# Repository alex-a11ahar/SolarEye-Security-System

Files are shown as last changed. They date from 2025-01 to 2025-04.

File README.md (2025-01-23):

## SolarEye-Security-System
### ECEN-403/404 Solar Security System Capstone Project

**A solar-powered security system with a motion-detecting camera. This system provides near real-time video feeds and send automated alerts for suspicious activity through a mobile app, enhancing safety in these areas.**

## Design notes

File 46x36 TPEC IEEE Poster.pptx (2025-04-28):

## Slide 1

SolarEye Security System
Alex Allahar, Zayan Prasla, Jackson Kitchel, Victor Igbokwe
Wonhyeok Jang

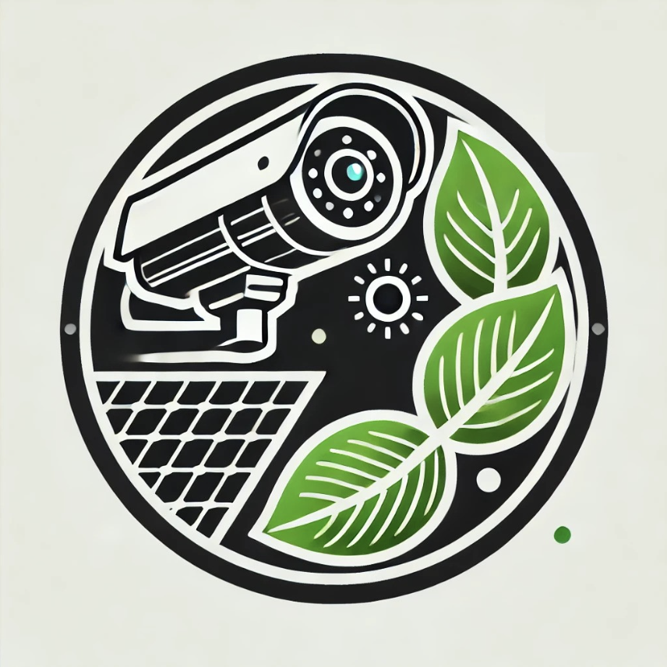
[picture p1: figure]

System Overiew
The SolarEye Security System uses solar-powered lighting, smart surveillance, and mobile alerts for real-time, automated, and low-maintenance security, ensuring safer, smarter public spaces.

Power Distribution
The Power Distribution system draws from a 12-volt battery, the system employs a buck converter [see Figure 3(A)] to step down the voltage to 5 volts, ensuring stable and efficient power delivery. This regulated 5-volt supply is essential for operating key components, including the charging ports and the Raspberry Pi. To enhance functionality, the LED lights are integrated through a dedicated PCB [see Figure 3(B)], which allows the Raspberry Pi to precisely control their operation. This setup enables seamless coordination between power distribution and system control, optimizing performance and efficiency.
A: Buck Converter PCB – Efficiently steps down 12V to a stable 5V supply.
B: Boost Converter PCB – Enables voltage regulation and control via the Raspberry Pi.

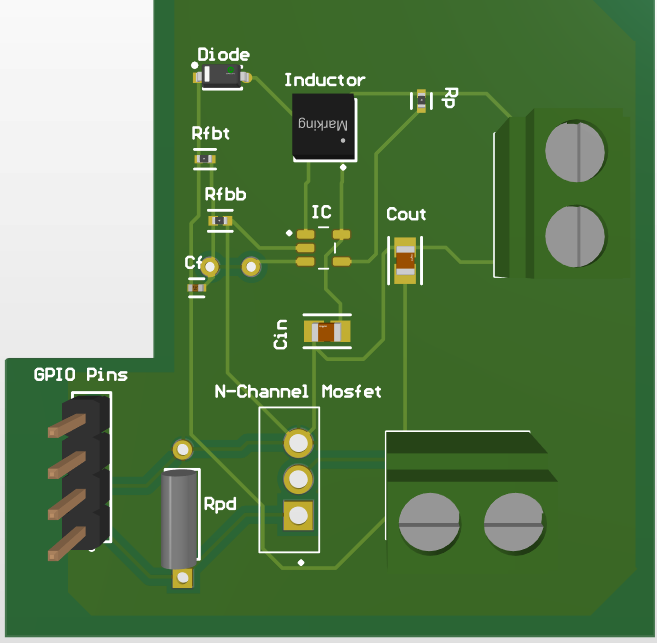
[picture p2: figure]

Solar Generation
The Solar power generation subsystem serves as the central power source within our project. The subsystem is responsible for the solar panel, charging circuit PCB and supplying power to the 12-volt battery. The 100W solar panel is connected directly to the charging circuit PCB which regulates the power and supplies the 12-volt battery with a safe and efficient supply voltage. Additionally, the voltage and current supply from the solar panel as well as the battery are monitored by the charging circuit. These data points are then output by the PCB to be read and processed by the Raspberry Pi 4B. The main components of the schematic below are as follows:
A: BQ24650, which serves as the Maximum Power Point Tracking (MPPT) aspect of the circuit
B: ACS723 current sensor IC chips, placed at the input and output of the circuit

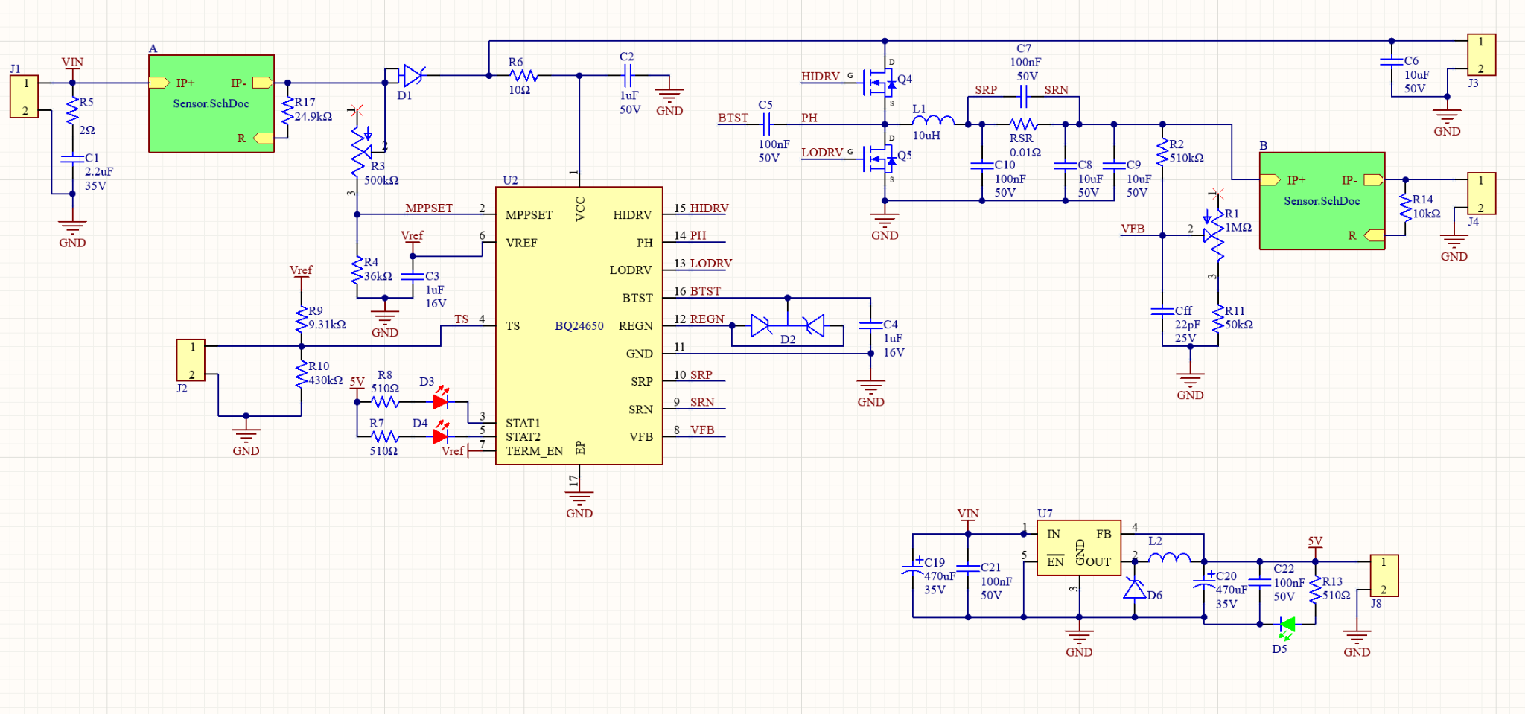
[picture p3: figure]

SolarEye App
The SolarEye App interfaces with the SolarEye Security System via Firebase, allowing comprehensive control over the system's camera and LED deterrence features. The home page provides an overview of Event History and Charging Statistics for the Solar Panel and Battery. In the Event History section, all recorded events are listed, complete with timestamps and event types. To ensure maximum security, the app's backend is fortified with email verification, two-step authentication, and SMS verification.

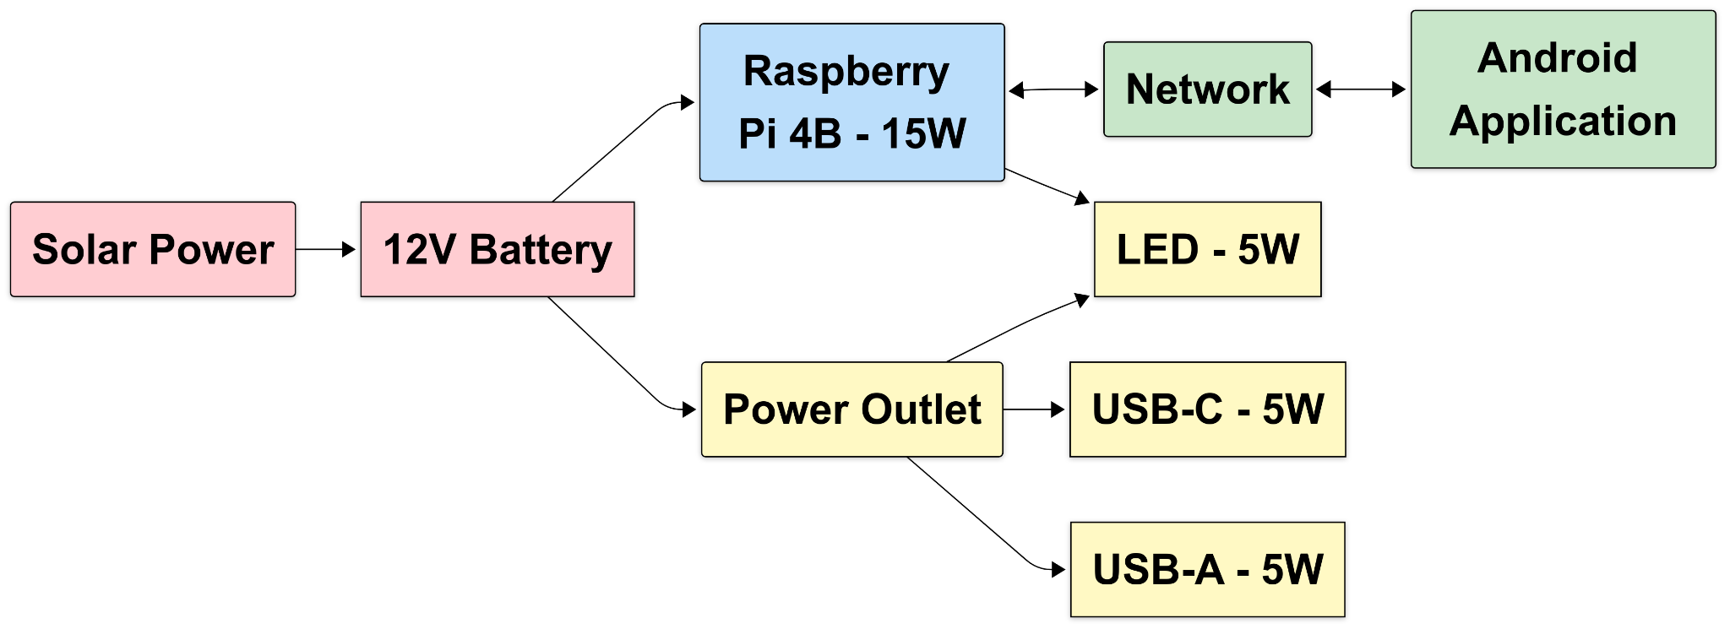
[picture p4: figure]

Figure 1. System Diagram

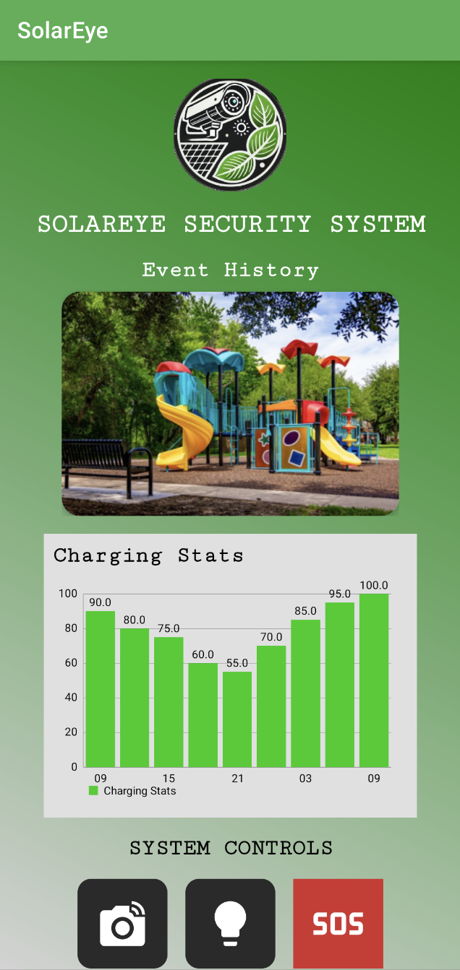
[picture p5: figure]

Figure 7. SolarEye App Home Page

Security
The SolarEye Security System has two modes: Passive Security and Active Surveillance. In Passive Mode, a PIR sensor triggers automated video capture, event logging, and Firebase storage. In Active Mode, users enable real-time streaming with OpenCV motion detection, sending alerts to Firebase for immediate response. This ensures efficient, continuous monitoring with optimized power use.

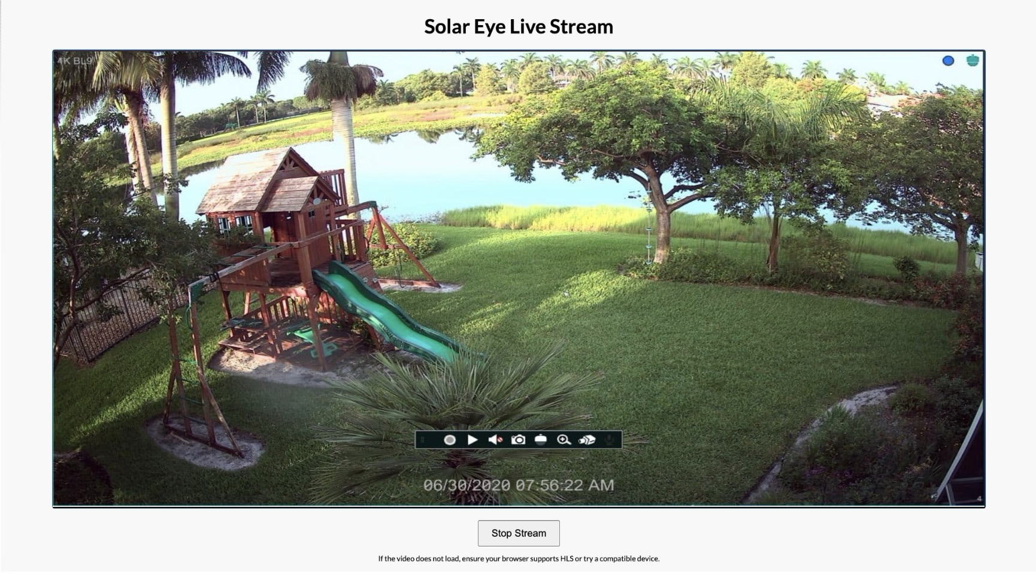
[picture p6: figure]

Figure 2: Livestream Layout

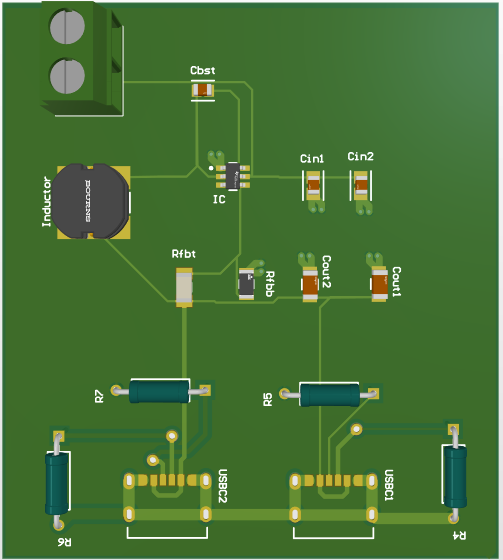
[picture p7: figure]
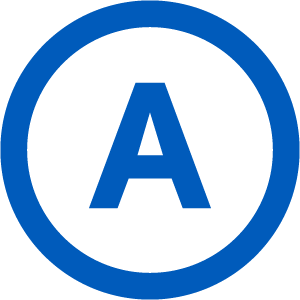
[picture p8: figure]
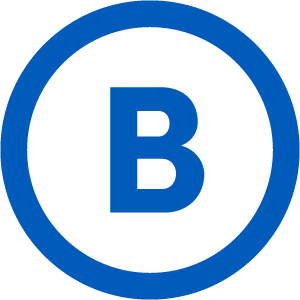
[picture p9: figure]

Figure 3. View of Printed Circuit Boards

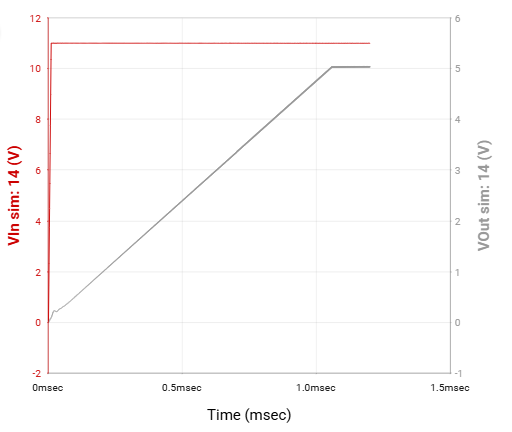
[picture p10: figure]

Figure 4.Simulation Results for the Buck Converter

Figure 5. Solar Power Charging Circuit Schematic

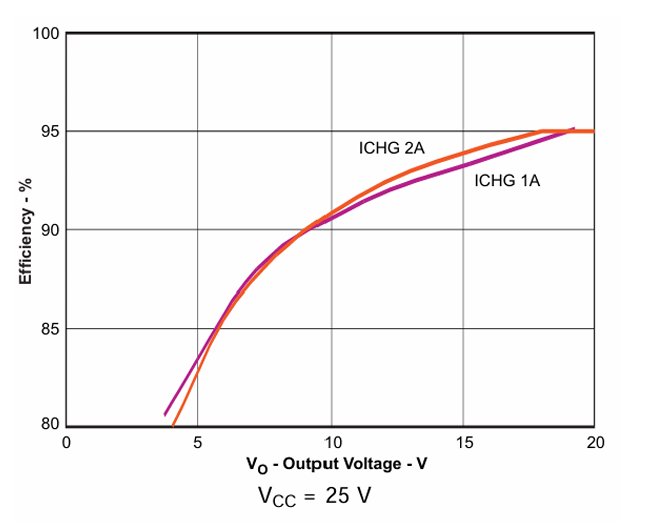
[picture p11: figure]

Figure 6. Solar Power Charging Circuit Efficiency vs Output Voltage (Taken from MPPT Spec Sheet)

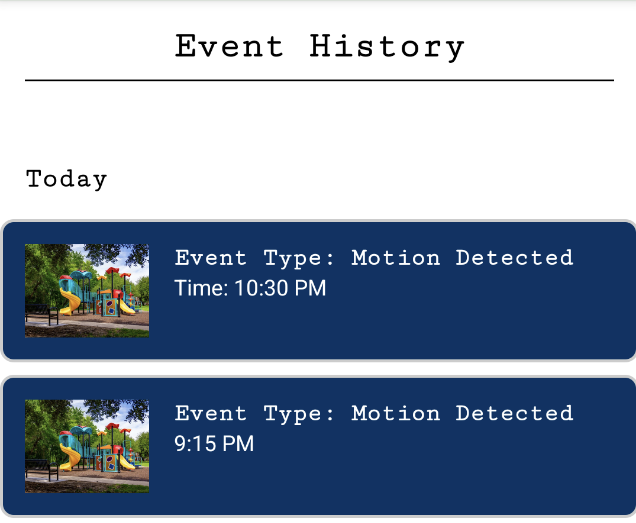
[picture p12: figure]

Figure 8. SolarEye App Event History Page

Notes: Fix Overview diagram

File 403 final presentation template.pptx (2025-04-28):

## ECEN 403 Final Presentation SolarEye Security System Team members: Alex Allahar, Victor Igbokwe, Jackson Kitchel, Zayan Prasla Sponsor: Dr. Jang


## Problem Overview

- A solar-powered security system with a motion-detecting camera. This system provides near real-time video feeds and send automated alerts for suspicious activity through a mobile app, enhancing safety in these areas.

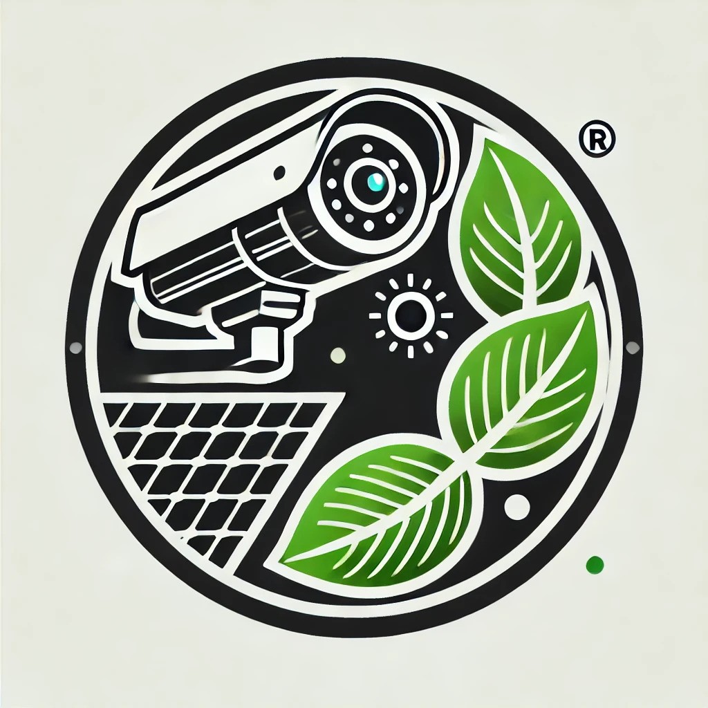
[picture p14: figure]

## System Diagram

Red - Jackson Kitchel (Power Generation)
Yellow - Victor Igbokwe (Power Distribution)
Blue - Alex Allahar (Detection)
Green - Zayan Prasla (Network & Application)

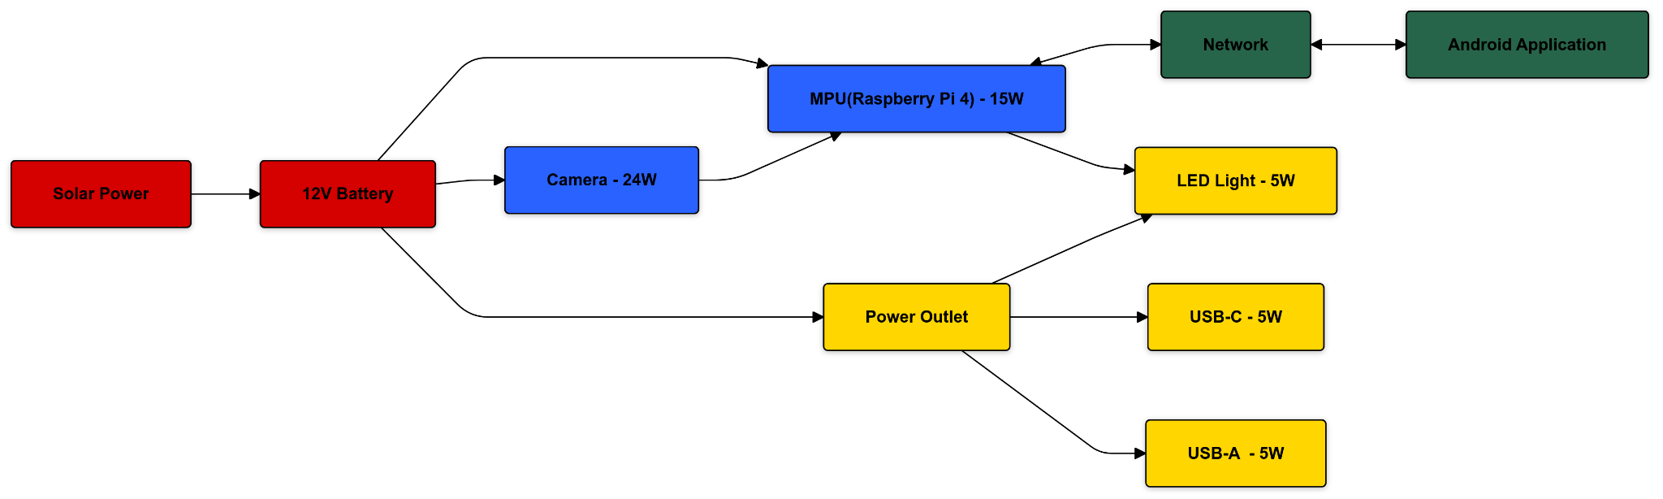
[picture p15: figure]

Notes: This is where task partition is stated, Alex

## Subsystem 1: Power Generation

- PCB responsible for power generation from the solar panel to the battery
- Battery supplies power distribution PCP with 12V
- Charging circuit automatically cuts on/off
- Provides MCU with voltage and current readings at the solar panel and battery

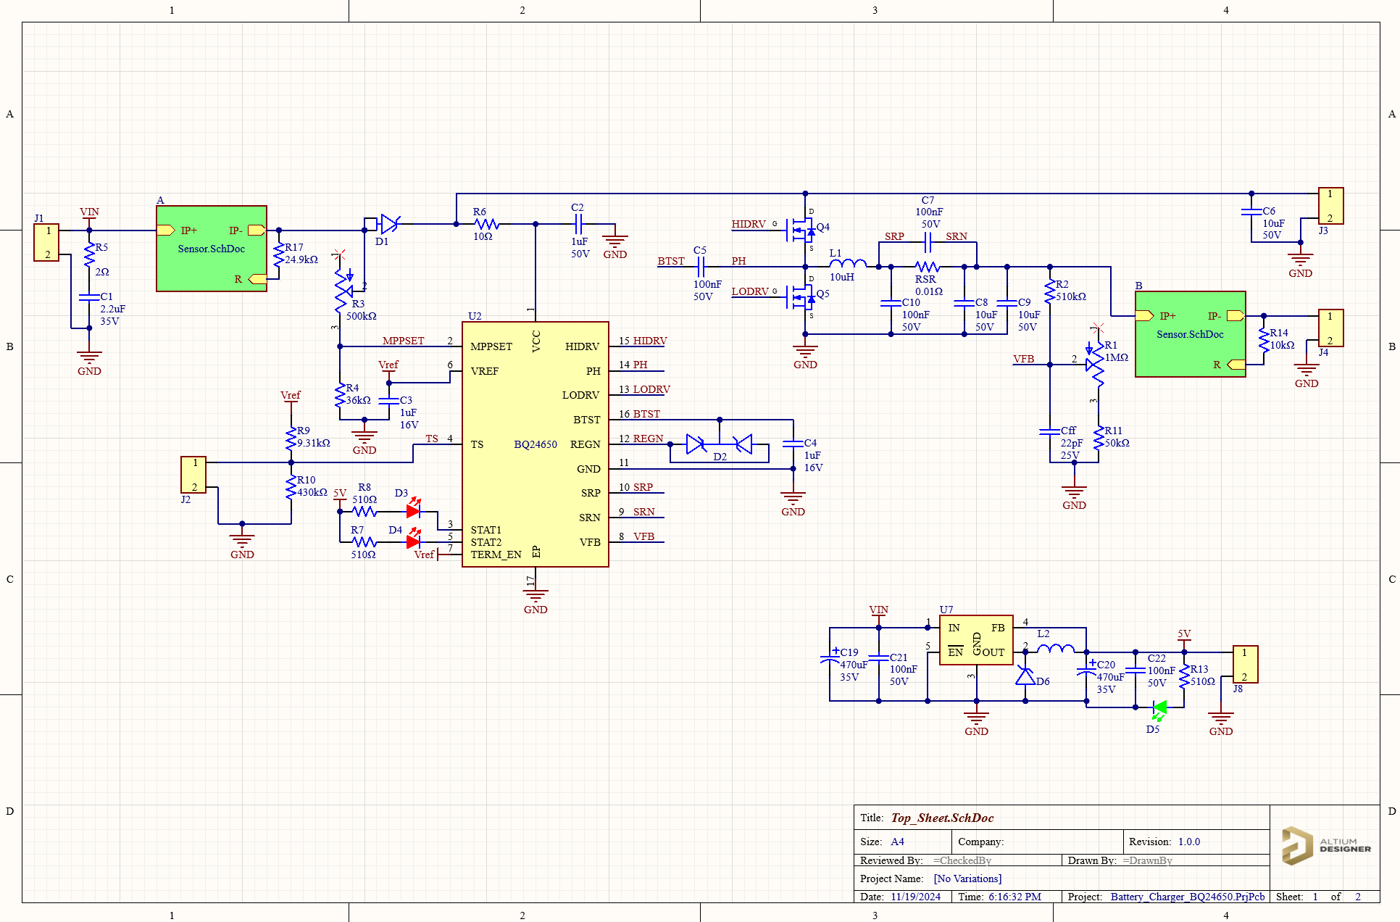
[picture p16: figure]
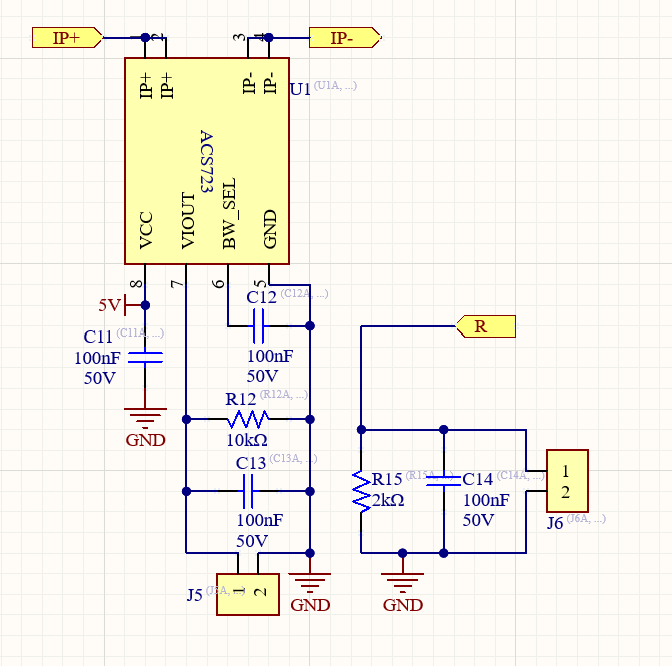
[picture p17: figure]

## Subsystem 1: Power Generation

- Ongoing Tasks:
  - First PCP scrapped
  - Soldering and testing PCB (ie. short circuit, continuity)
- To do in 403:
  - Battery charging test
  - Cut on/off test
  - Demo
- To do in 404:
  - Integrate power with distribution subsystem
  - Integrate voltage/current readings with MCU subsystem

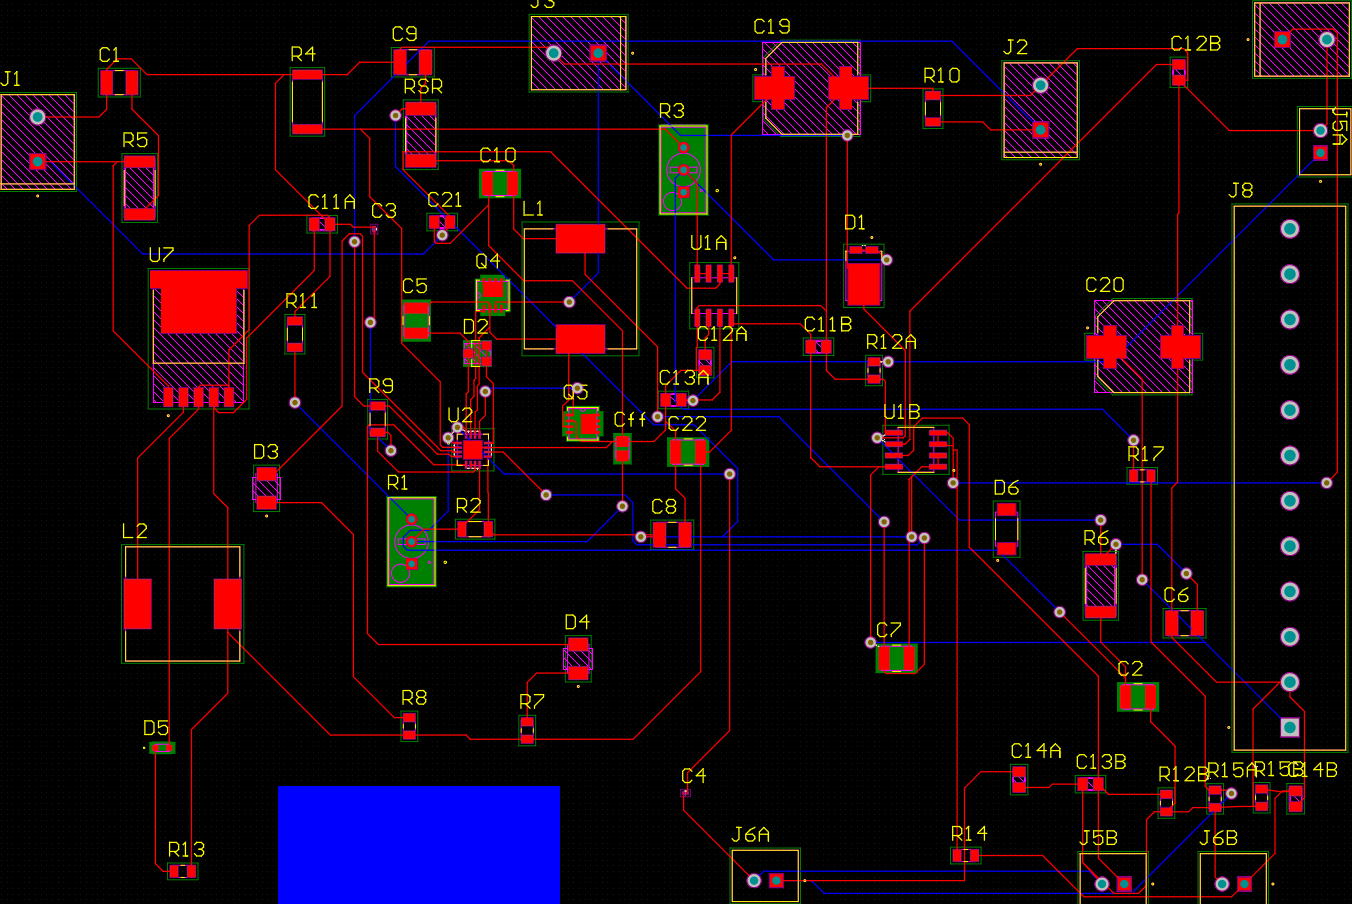
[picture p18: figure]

## Subsystem 2: Power Distribution

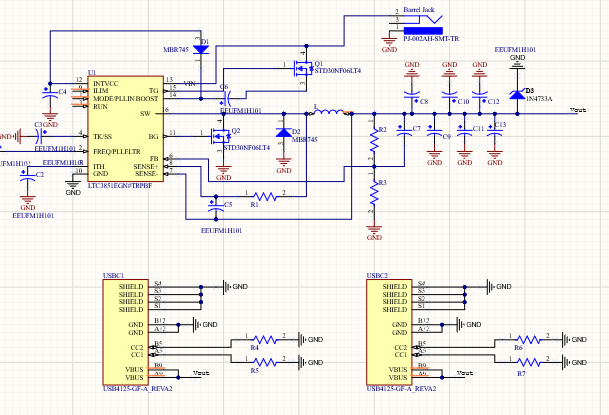
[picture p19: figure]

## Power Distribution Cont.

Completed Tests
- Continuity Test: Use a multimeter to check continuity between connected pads and traces to ensure no open connections exist.
- Short Circuit Test: Verify there are no shorts between the power (5V and 12V rails) and ground. Measure resistance between 5V and GND and 12V and GND. It should not show a short (low resistance).
Concerns
- Vin Connection: Experiencing difficulties with the connection between the MOSFET and the Vin pin of the IC chip.
Proposed Solution
- Perf Board: Use an external Perf board to solder a connection between the mosfet and Vin.
To Do (403)
- Output Voltage Test
- Load Test
To Do (404)
- Voltage Regulator load Components
- Integration with other subsystems

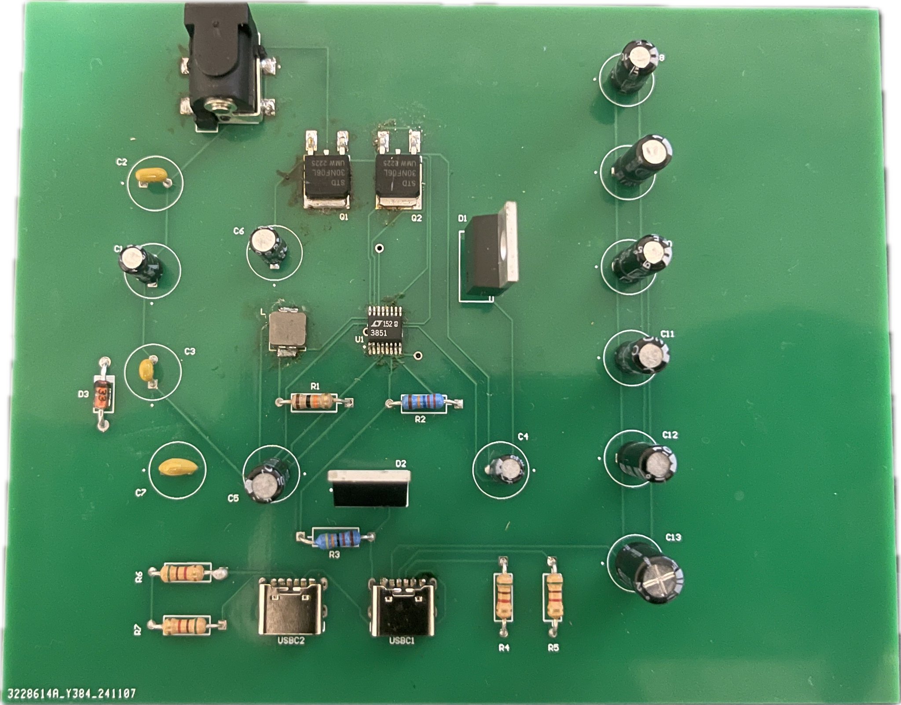
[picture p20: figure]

## Detection: Modes of Operations

Low-Power Mode
Passive (Security)
- PIR Sensor Activated
- Automated Video Capture
  - Fixed / Variable
- Generate Thumbnails
- Local Event History
- Store Footage on Firebase

Operational Mode
Active (Surveillance)
- User Activated
- Real-Time Video Stream
- OpenCV Motion Detection
- Send Alert to Firebase

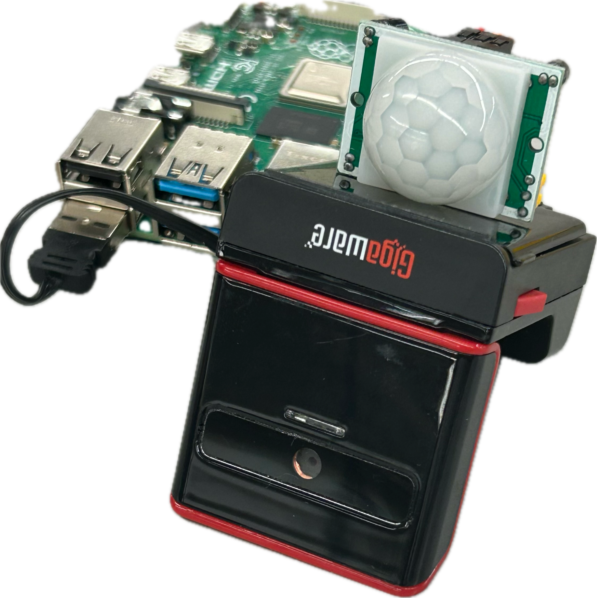
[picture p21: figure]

## Detection: Test Cases

Completed:
  - Validate PIR Sensor functional up to 5 ft, FOV, with a FOV of 120°
  - Minimize delay between motion detection and video capture stored on Firebase.
  - Measure Raspberry PI Memory and CPU Usage during Modes of Operation.
To-Do (403):
  - Passive Mode Output

## Subsystem 4: Software/App

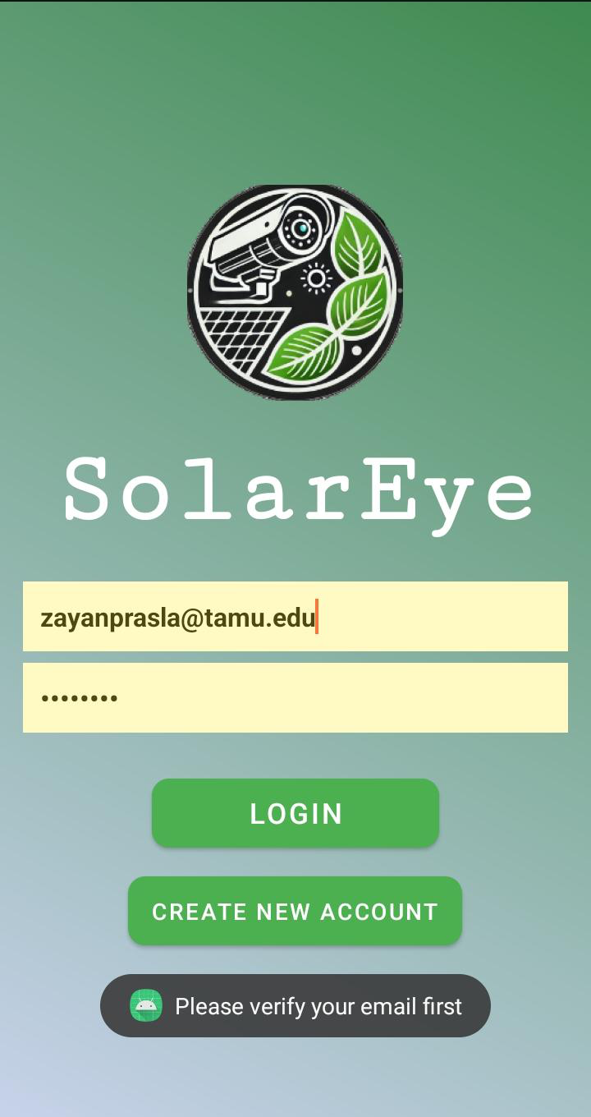
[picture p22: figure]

Login Page:
- User Login saved on Firebase Auth
- Email must be verified to login
- User remains logged in until they manually log out

Email Verification:

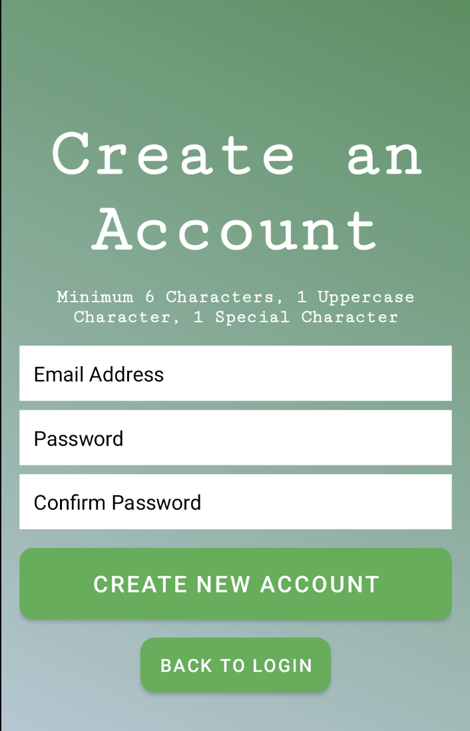
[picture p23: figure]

Account Creation:
- Email Verification
- Verification Link expiration
- Password Policy

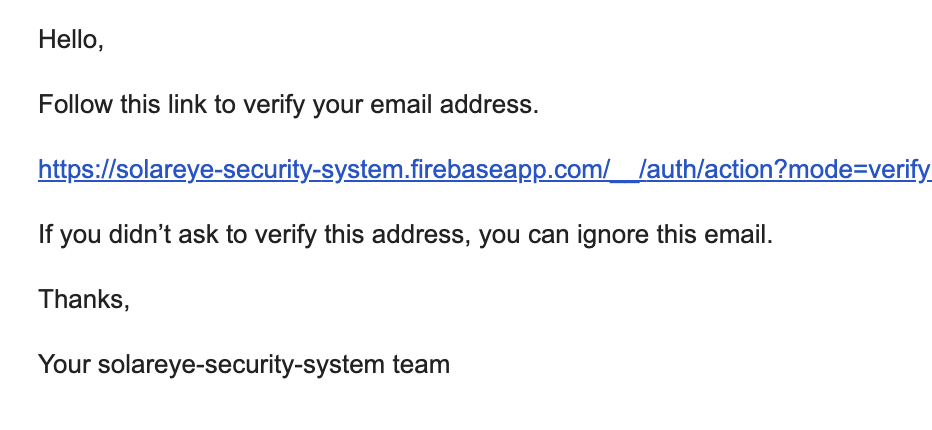
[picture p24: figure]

## Subsystem 4: App Main Page


Main Page:
- Latest thumbnail displayed
- Charging Statistics
- System Controls


Event History:
- Events sectioned by date recorded
- Event Type and Time


Settings:
- Log Out
- Email Change
- Password Reset

## Subsystem 4: App System Controls


- On/Off controls for Camera and LED Light (not yet connected)
- SOS Emergency Call (connected directly to device)

## Execution and Validation Status


## Remaining Tasks

- Summarize what remains to be completed for your subsystem design, assembly, test, and validation by Project Demo date.
- Summarize what key design activity from each subsystem will be completed in 404 (eg. fabrication and assembly of final PCB, full ML model training, in-situ sensor calibration, enclosure design and fabrication, mount 3d-printing)

- Software: FAQ section is left. In 404 the app will be connected to the security system, retrieve live data from Firebase Firestore, and have a better front User Interface.
- Microprocessor/Detection:
- Power Generation:
- Power Distribution:

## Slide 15


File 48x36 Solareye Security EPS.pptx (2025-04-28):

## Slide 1


EQ39

SolarEye Security System
Alex Allahar, Zayan Prasla, Jackson Kitchel, Victor Igbokwe
Wonhyeok Jang


Electrical Engineering

System Overiew
An autonomous solar‑powered, motion‑activated camera system that delivers live video feeds and instant app alerts for reliable off‑grid surveillance.

Power Distribution
The Power Distribution system draws from a 12-volt battery, the system employs a buck converter [see Figure 3(A)] to step down the voltage to 5 volts, ensuring stable and efficient power delivery. This regulated 5-volt supply is essential for supplying adequate power to the Raspberry Pi. To enhance functionality, the LED lights and cooling fans are integrated through a dedicated relay control PCB [see Figure 3(B)], which allows the Raspberry Pi to precisely control their operation. This setup enables seamless coordination between power distribution and system control, optimizing performance and efficiency.
A: Buck Converter PCB – Efficiently steps down 12V to a stable 5V supply.
B: Relay Control PCB – Allows the user to control via the Raspberry Pi.


Figure 3. View of Printed Circuit Boards

Solar Generation
The Solar power generation subsystem serves as the central power source within our project. The subsystem is responsible for the solar panel, charging circuit PCB and supplying power to the 12-volt battery. The 100W solar panel is connected directly to the charging circuit PCB which regulates the power and supplies the 12-volt battery with a safe and efficient supply voltage. Additionally, the voltage and current supply from the solar panel as well as the battery are monitored by the charging circuit. These data points are then output by the PCB to be read and processed by the Raspberry Pi 4B. The main components of the schematic below are as follows:
A: BQ24650, which serves as the Maximum Power Point Tracking (MPPT) aspect of the circuit
B: ACS723 current sensor IC chips, placed at the input and output of the circuit


SolarEye App
The SolarEye App interfaces with the SolarEye Security System via Firebase, allowing comprehensive control over the system's camera and LED deterrence features. The home page provides an overview of Event History and Charging Statistics for the Solar Panel and Battery. In the Event History section, all recorded events are listed, complete with timestamps and event types. To ensure maximum security, the app's backend is fortified with email verification, two-step authentication, and SMS verification.


Figure 7. SolarEye App Home Page

Figure 1. System Diagram

Modes of Operation
Low Power Mode (≈ 32.8 h runtime)
- Logs only when an event occurs and its duration (no video). Timestamps and durations available in the app; LED deterrence flashes rapidly.
Motion Detection Mode (Default) (≈ 30.7 h runtime)
- Continuously monitors via PIR sensor, captures short videos on motion, and uploads them.
- Process: PIR → log event → record until 2 s after no motion → save H.264 locally → convert & upload MP4 to Firebase → app shows time stamped video history.
Livestream Mode (≈ 22.2 h runtime)
- Provides real‑time video streaming on demand.
- Tap “Livestream”; Pi starts HLS streaming and sends the link to the app.


Figure 4. Buck Converter Voltage Regulation graph

Figure 5. Solar Power Charging Circuit Schematic


Figure 6. Solar Power Charging Circuit Efficiency vs Output Voltage (Taken from MPPT Spec Sheet)


Figure 8. SolarEye App Event History Page


Figure 2. Livestream UI Layout

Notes: A battery-powered IoT security system offering three operation modes that balance power consumption against functionality.

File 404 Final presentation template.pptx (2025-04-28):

## ECEN 404 Final Presentation Team 65: Solar Playground with Security System Team Members: Zayan Prasla, Alex Allahar, Jackson Kitchel, Victor Igbokwe Sponsor: Wonhyeok Jang TA: Zian Wang

## Problem Overview

A solar-powered security system with a motion-detecting camera. This system provides near real-time video feeds and sends automated alerts for suspicious activity through a mobile app, enhancing safety in these areas. It solves the problem of unreliable surveillance in remote or off-grid locations by offering an autonomous, low-maintenance solution.


## Integrated Project Diagram


Figure 1: Full System Overview

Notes: Picture (or collection of pictures) or drawing of system
Major components labeled
Show how user connects (ui screens, pictures, etc)
Label major connections/interfaces

## Integrated Project Diagram (Hardware)


Figure 2: Hardware Overview

Intake Fan

Buck Converter PCB

Solar Charging PCB

Power Switch

Relay control PCB

Raspberry Pi 4 B

CSI Pi Camera

PIR Sensor

Exhaust Fan

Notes: Picture (or collection of pictures) or drawing of system
Major components labeled
Show how user connects (ui screens, pictures, etc)
Label major connections/interfaces

## Integrated System Diagram (Software)


Figure 3: Homepage with updating Event thumbnail and updating Charging Statistics

Figure 6: Modes of Operation and System Controls with successful communication


Figure 4: Event History Page with live stream capability and playable videos

Figure 5: Video Player from the app


## Power Generation - Jackson Kitchel

Designed & Built:
- Designed and built a charging circuit capable of charging a 12V battery using a 100W solar panel.
- Implemented Maximum Power Point Tracking (MPPT) using the BQ24650 IC chip
- Implemented 2 current and voltage sensors using the ACS723 IC chips along with ADC
Tested & Validated:
- Charging voltage test completed along with high/low voltage cutoffs. Sensors tested with MCU. Battery life to be tested.
Challenges & Solutions:
- Redesigned charging circuit to solve incorrect capacitor problem, along with making the circuit more compact.

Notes: Flask (HTTP)

Serves web interface for live video access and control

Runs lightweight, multithreaded server for responsiveness

FFmpeg + HLS Streaming

Captures video via libcamera-vid and streams with FFmpeg

Outputs low-latency .m3u8 segments for browser playback using hls.js

## Power Generation - Jackson Kitchel


Figure 7: Charging Circuit Schematic

Figure 8: Current Sensor Schematics


Figure 9: PCB Design

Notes: Flask (HTTP)

Serves web interface for live video access and control

Runs lightweight, multithreaded server for responsiveness

FFmpeg + HLS Streaming

Captures video via libcamera-vid and streams with FFmpeg

Outputs low-latency .m3u8 segments for browser playback using hls.js

## Power Generation - Jackson Kitchel

Figure 10: Charging Voltage vs Solar Panel Voltage Graph

Figure 11: Old PCB Design


Figure 12: Charging Voltage Output


Figure 13: New PCB Design

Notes: Flask (HTTP)

Serves web interface for live video access and control

Runs lightweight, multithreaded server for responsiveness

FFmpeg + HLS Streaming

Captures video via libcamera-vid and streams with FFmpeg

Outputs low-latency .m3u8 segments for browser playback using hls.js

## Power Distribution - Victor Igbokwe

Designed & Built:
- Designed and built a buck converter using the Texas Instruments TPS563200 DCR regulator to provide stable 5V output for embedded systems.
- Implemented a relay control module using an N-channel MOSFET to act as a switch, enabling the Raspberry Pi to control the on/off state of external loads.
Tested & Validated:
- Buck converter Voltage and load regulation tests, Relay Control module Load regulation test, measured time delay between Pi signal and device activation.
Challenges & Solutions:
- Safety for repairs: Installed a switch button to the Junction box to shut down all power flowing through the system
- Buck Converter: Re-designed to ensure correct functionality

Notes: Flask (HTTP)

Serves web interface for live video access and control

Runs lightweight, multithreaded server for responsiveness

FFmpeg + HLS Streaming

Captures video via libcamera-vid and streams with FFmpeg

Outputs low-latency .m3u8 segments for browser playback using hls.js

## Power Distribution - Victor Igbokwe


Figure 14: Voltage regulation graph

Initial MPU Remote Access time delay | 1.26 minutes
Raspberry PI 4B input Voltage Range(V) | 4.75 - 5.25


Figure 15: Buck Converter


Figure 16: Load regulation graph

* 5% Tolerance

## Power Distribution - Victor Igbokwe


Figure 17: Relay control load regulation graph

Time delay between MPU signal and device activation
0.4 seconds


Figure 18: Relay control module PCB


Figure 19: Use of N-Channel Mosfet diagram

## Edge Processing Unit - Alex Allahar

Designed & Built:
- Integrated PIR sensor (I2C), voltage sensor (I2C), camera (CSI), LED and fans (GPIO) with a Raspberry Pi 4B to enable the following features:
  - Low-Power Mode
  - Motion Detection
  - Live Streaming
  - LED Deterrence
Tested & Validated:
- Calibrated sensors & fans, ADC communication, Camera quality, power consumption, overall hardware-software latency
Challenges & Solutions:
- CPU Overload: Solved with multi-threading and modes of operation controls.
- MPU Overheating: Fans for Overheating.
- Camera: Replaced Camera (USB to CSI), video format selection, Live streaming delay

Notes: Expand on the Modes of Operation Points

Livestream:
Host a Flask Server with HTTP web interface for live video access and control
Captures video and streams with FFmpeg with HLS browser playback for viewing via the HTTP Flask Url

## Edge Processing Unit - Alex Allahar

Figure 20: Requirements Validation Table

Requirements | Target | Measured | Status
Motion to App Delay | < 1 s | 0.0784 s | Passed
Video Upload Latency | < 3 s | 1.2951 s | Passed
Real Event vs. Video Capture Ending | < 5 s | 4.03 s | Passed
Livestream Delay | < 5 s | ~7.8 s | Failed
Motion Detection Range | 12 ft | 16 ft | Passed
Fans Power Consumption | < 5 W | 8.8 W | Failed
Pi Power Consumption (Low Power) | < 20 W | 9.4 W | Passed
Pi Power Consumption (Default) | < 20 W | 10.75 W | Passed
Pi Power Consumption (Livestream) | < 20 W | 18.25 W | Passed

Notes: Validation Meaning:
System provides near real-time motion detection to alert system with minimal latency
The biggest downside to the user experience is the Live Streaming delay
The power consumption of all three modes of operation are less that 20 W, this target was chosen due the battery specs if less that 20 W are at max constant use for a given mode of operation the system in theory should be able to run for 25 hrs on the battery ensure that it can survive the night while the panel is unable to charge.

Power consumption was calculated by measuring the current of the system under load in Lab.

## Android Application - Zayan Prasla

Designed & Built:
- Created a secure Firebase Authentication system for account creation, email verification, password reset, password policy and persistent login
- Developed camera, LED, and SOS control features, with Modes of Operation for system power usage
- Implemented real-time event history with video thumbnail previews and video playback
Tested & Validated:
- Verified user authentication flows, password policies, and email verification timeouts
- Confirmed Firestore integration for reading and writing system control states
- Ensured proper display and playback of video thumbnails from Firestore Database URLs
Challenges & Solutions:
- Firestore path issues: Fixed with proper document structure and logging
- Video Player issues: Solved by having the mcu create video url links for the app to open from Firestore Database.

## Android Application - Zayan Prasla

App Features Validation Table:

Requirements | Spec | Measured
Authentication Timeout | Email verification link expires in 5 min | Verified expiration at ~5:01 min
Password policy enforcement | Min 6 char, 1 capital, 1 symbol, 1 number | 100% rejection rate on invalid attempts
Video event thumbnail loading | Thumbnail shown within 2 sec | Avg load time: 1.2 sec, max: 1.8 sec
Battery graph recency | Only last 24h voltage data shown | Consistently accurate range filter applied
Mode change response (Firestore write) | Update reflected in < 1.5 sec | Avg: 0.9 sec, Min: 0.6 sec, Max: 1.4 s

Figure 21: App Features Validation Table:

## Integrated System Results

End-to-End System Operation (Low Power):
Low Power Mode Predicted Run Time ≈ 32.8 hours
Lower Power Mode (User Experience):
- Able to see when the event occurred, and duration via but no video.
- LED Deterrence is available, flashes the LED rapidly.


Figure 22: LED Deterrence Active


Figure 23: Event History

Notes: This section shows end-to-end system operation
Show and provide details on a few important end-to-end use scenarios that you developed and validated. Giving results (be quantitative here – results for key performance indicators … time to complete task, overall accuracy of task, success/fail measures)

About 2 minutes total

The run time is calculated given the power consumption of Pi combined with power consumption of Fans

## Integrated System Results

End-to-End System Operation (Default):
Motion Detection Mode Predicted Run Time ≈ 30.69 hours
Motion Detection Mode (Pipeline):
- PIR Sensor detects motion → event is logged → camera starts recording → recording stops after 2 seconds of no motion → video saved locally(h264) → uploaded to Firebase(mp4) → app receives video with timestamp → user views it in event history.


Figure 24: Motion Detection Capture


Figure 25: Notification Packaged for App

Figure 26: Event History

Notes: This section shows end-to-end system operation
Show and provide details on a few important end-to-end use scenarios that you developed and validated. Giving results (be quantitative here – results for key performance indicators … time to complete task, overall accuracy of task, success/fail measures)

If Low Power Mode or Livestreaming are triggered by the user, motion detection will be active.

About 2 minutes total

The total Run Time is calculated by combine hardware component power consumption and Pi power consumption given the 50Ah 12V battery

## Integrated System Results

End-to-End System Operation (Livestream):
Livestream Mode Predicted Run Time ≈ 22.18 hours
Lower Power Mode (User Experience):
- User click Livestream Button - HTTP Server Activates - Pi starts HLS Stream Protocol - Stream HTTP Link create/sent to app - user can access stream by clicking on the Link

Figure 25: LIvestream HTTP Server Startup

Figure 26: LIvestream HTTP Link to Firebase


Figure 27: LIvestream UI

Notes: This section shows end-to-end system operation
Show and provide details on a few important end-to-end use scenarios that you developed and validated. Giving results (be quantitative here – results for key performance indicators … time to complete task, overall accuracy of task, success/fail measures)

About 2 minutes total

Livestream:
Host a Flask Server with HTTP web interface for live video access and control
Captures video and streams with FFmpeg with HLS browser playback for viewing via the HTTP Flask Url

## Conclusions

Changes from original System design:
- Buck Converter IC chip change leading to re-design of Buck converter
- Relay control module PCB added to system design
- Charging Circuit redesigned to solve capacitor problem and consolidate PCB
- ADC added to system to allow communication between current sensor IC chips and MCU
Current Status:
- Integration Complete
- Operational Testing Complete
- Validation Complete
- Edge Case Testing in Progress

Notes: List issues encountered that required changes from system described in Conops, FSR/ICD and resulting system design changes
Current status (eg. integration/test/validation complete; Integration complete, but BT comm not fully validated; Repeating testing for replacement PCB, integration/validation to be completed in 1 week)

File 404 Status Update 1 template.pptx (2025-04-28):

## Team 65: Solar Playground with Security System Bi-Weekly Update 1 Team Members: Zayan Prasla, Alex Allahar, Jackson Kitchel, Victor Igbokwe Sponsor: Wonhyeok Jang TA: Zien Wang


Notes: Michelle

## Project Summary

A solar-powered security system with a motion-detecting camera. This system provides near real-time video feeds and send automated alerts for suspicious activity through a mobile app, enhancing safety in these areas.


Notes: Kyle

## Subsystem Overview

Red - Jackson Kitchel (Power Generation)
Yellow - Victor Igbokwe (Power Distribution)
Blue - Alex Allahar (Microprocessor & Sensors)
Green - Zayan Prasla (Network & Application)


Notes: Edge processing unit for the system.

## Major Project Changes for 404

- Removed Object Detection
- LED Deterrence
- Adding Cooling

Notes: Bullets on MAJOR changes in project direction due to learning from 403. If stuff didn’t work out now is the time to redirect
-- eg custom to COTS, MCU changes, application change, major change in communication technology, …

## Project Timeline


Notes: High level figure showing where you are at in the project, what’s completed, what’s underway – it should take about 30 seconds to summarize where you are in the timeline

-- Save discussion for subsystem update
-- Save detail for execution plan & validation plan status

## Power Generation Jackson Kitchel

Accomplishments since 403 | Ongoing progress/problems and plans until the next presentation
PCP has been updated to address issues that were found in 403. Parts and PCB has been ordered. | - Solder and test new PCB upon arrival. - Integrate with other subsystems.

## Power Generation Jackson Kitchel

- Problem with footprint and missing
trace to be fixed with new order


## Power Distribution Victor Igbokwe

Accomplishments since 403 | Ongoing progress/problems and plans until the next presentation
Buck Converter system experienced issues due to complexity of IC chip that. New PCB has been designed and ordered using a Texas Instruments IC chip. | Soldering and testing my new buck converter system. Design and order a new PCB that will implement using an N-Channel Mosfet as a switch to control the Security light.

## Power Distribution Victor Igbokwe


Still Developing:
Using N-channel as a switch
- Common Ground between microcontroller and Power supply
- Pull-down resistor at the output pin.
- Setting the output pin to High will allow current flow while setting it to low will disrupt current flow.


## Microprocessor & Sensors Alex Allahar

Accomplishments since 403 | Ongoing progress/problems and plans until the next presentation
Tested and Validation CSI Camera | Integration of Firebases Designing the cooling and housing for MPU, Camera, & Sensors.

## Microprocessor & Sensors

Low-Power Mode
Works
- GPIO Sensors
- Automated Video Capture
  - Fixed / Variable
- Thumbnails Generation
- Local Event History
- Cloud Video Storage

Streaming Mode
Works
- Real-Time LIve Stream
- Live Stream Web Server
- OpenCV Motion Detection
- App Notification
Still Developing
- User Activation via App

## Subsystem 4 Application Zayan Prasla

Accomplishments since 403 | Ongoing progress/problems and plans until the next presentation
Removed fixed event history examples from 403 and connected it to Firebase for live updates. Added reset password for the login page and connected it via backend to the user’s specific email. | App to microprocessor connection via Firebase Camera and LED controls Live stream Constantly improving frontend UI as well

## Subsystem 4 Application Zayan Prasla

Backend/Security
Works
- User Login and Account Creation
  - Password Policy Enforced
  - User accounts stays logged in until manually logged out
- Email Verification
  - Verification link expires after 5 minutes
- Internet Connection
- Password Reset
- Email Address Change
- Event History connected to Firebase Realtime Database
Still Developing
- App to Microprocessor connection
- New Sign-in Methods
- SMS Verification
- 2-step verification

Frontend
Works
- Login, Create Account, Home, Settings, and Event History pages all work
- SOS button
- Error messages for when password policy is not properly followed or
- User friendly UI
Still Developing
- Improvements to the home page UI is needed
- Camera and LED buttons are visible but not yet functional
- Charging Statistics

## Parts Ordering Status


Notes:
Most parts orders for 404 should be placed very soon.
Provide summary of what is ordered but not received and what remains to be ordered.
When do you expect to have all parts?

## Execution & Plan


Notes: Execution plan
Your team planned milestones for completion of any remaining subsystem functionality, integration of specific subsystems, test, and validation plans should be presented.
Milestones should have owners … things like final integration can be group owned
Gantt chart – should indicate some 404 progress.
Try to complete all subsystem function in next 3 weeks.
Try to complete all integration 2 weeks before demo to allow for system validation and documentation

## Thank You

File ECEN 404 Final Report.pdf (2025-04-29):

# SolarEye Security System

## Alex Allahar Victor Igbokwe Jackson Kitchel Zayan Prasla

## CONCEPT OF OPERATIONS

REVISION – Final Report
Nov 29, 2024

CONCEPT OF OPERATIONS

FOR

## SolarEye Security System

TEAM <65>

APPROVED BY:

_____________________________
Alex Allahar | Date

_____________________________
Prof. Kalafatis | Date

_____________________________
T/A | Date

Change Record

Rev . | Date | Originator | Approvals | Description
- | 09/11/2024 | SolarEye Security System | | Draft Release

Table of Contents
List of Figures (https://docs.google.com/document/d/1O-yeo_oHaWDs89FKLMGhLaOKlO6qjsMC/edit#heading=h.tyjcwt) | 5
1. Executive Summary | 6
2. Introduction
3. Operating Concept
4. Scenario(s)
5. Analysis

List of Figures

/.,

## 1. Executive Summary

Maintaining a safe play area in neighborhoods, parks, and playgrounds is essential for children’s well-being and safety. Contrary to using a security officer or relying on bystanders to keep these areas safe, the SolarEye Security System provides an automated surveillance system that can monitor and report potential threats to security. The system will provide lighting and outlets whenever anyone is present in the park, and have the ability to send camera footage to a mobile device via an app. This SolarEye Security System app will provide a user interface including alerts and manual controls of the system. Additionally, this system will be solar powered in order to be self-sustained and off the grid. The system will feature various modes of operation to decrease battery usage during slow periods or after hours. Overall, the SolarEye Security System will provide a more inclusive and safe environment for local neighborhood play areas.

## 2. Introduction

This document is an introduction to the SolarEye Security System, a system that features an advanced security system designed for playground surveillance. The SolarEye Security System app provides real-time monitoring and alerts users of any detected security threats. With its eco-friendly, automated technology, the system reduces the need for human security patrols, ensuring constant surveillance once the system is in operation.

### 2.1. Background

Security systems today consist of cameras that are turned on and running continuously. The data from these cameras are stored on-site or are being streamed and monitored in real time by a designated personnel. In order to save money, power, memory storage and manpower, most businesses opt for cheaper systems. Society continues to take steps towards automating remedial tasks.

The SolarEye Security System aims to provide reliable security and surveillance to local neighborhood play areas such as parks and schools. The system will be able to actively monitor the areas of interest with the use of LED lights and a camera. When motion is detected at night during unauthorized hours the LED lights will draw more power from the battery and shine brighter to act as a stronger source of light for people to deter wrong doers by alerting them to the camera that is watching them. Footage from the camera will be accessible through the android application. The system will also power various charging outlets for park goers to be able to charge their devices.

### 2.2. Overview


Figure 1: SolarEye Security System Flow Chart

The SolarEye Security System is an advanced, eco-friendly solution for playground security that ensures both active and passive surveillance in local neighborhood play areas. By utilizing automated camera detection and image processing, the system monitors for abnormalities and alerts administrators and users via the SolarEye Security System app, providing event history, and app notifications. The SolarEye Security System features a network to collect image data and notify users, while responsive LED lights and charging outlets enhance user interaction and security on-site. The LED lights adjust brightness when motion is detected at night, serving as a deterrent to trespassers and illuminating the playground for park goers. The system will also power device charging stations to ensure park goers such as parents/guardians have fully charged devices in the case of an emergency. Designed to be self-sustainable, the SolarEye Security System eliminates the need for human surveillance, offering reliable surveillance to protect local play areas in parks and schools.

### 2.3. Referenced Documents and Standards

- http://www.solarabcs.org/
- Solperk 20W solar panel and solar battery charger.https://solperk.shop/
- https://docs.rs-online.com/b1fb/0900766b816fa153.pdf
- IEEE Wi-Fi communication standards: IEEE 802.11

## 3. Operating Concept

### 3.1. Scope

The SolarEye Security System enables self-sufficient automated security of local play areas. Through active surveillance, the area of interest will be monitored for potential security threats, provide recent video footage, and notify park goers with alerts.While motion is detected the camera will be operational. During this time the camera will send near real-time video footage to the microprocessor via a network. Locally, the video data will be analyzed using a basic threat detection model. The microprocessor will relay the security threat detected, and notify users of the SolarEye Security System app. The system will provide a responsive LED to provide active deterrence, depending on the threat detected. The SolarEye Security System's self-sustainable and automated nature will be a versatile solution to increase security and surveillance in local neighborhood playgrounds and parks.

Figure 2: Shirewood Park

### 3.2. Operational Description and Constraints

The SolarEye Security System is designed to be a self-contained autonomous security system for local, neighborhood playgrounds. The use of solar power will allow this system to function independently of external power systems. The system will implement image processing to detect possible threats, and alert users. A LED will be used as a form of deterrence, based on the type of threat detected. The potential constraints from this operational description are as follows:
- The system needs to be in an environment with sufficient sunlight every 16 hours to continuously power to load devices.

- The playground must be smaller than 300 square feet, for each camera unit to get full coverage.
- If the playground has a canopy it should be at least 12 feet above the base of the playground, to allow for the camera to have full visibility of the playground.
- The budget of 400$ restricts the quality of materials and parts used to construct the system.
- The system will be designed to function in normal Texas weather conditions, the system’s functional in other conditions and climates is not guaranteed.

### 3.3. System Description

Solar Power Generation: This subsystem provides power to the load devices. The load devices in the system are the camera, outlets, LED, microprocessor, and sensors. The solar panel will charge the battery during the day, which will allow the system to operate at night after authorized playground hours. This subsystem aims to provide an eco-friendly and self-sustained power system to allow this system to not rely on the local play area power infrastructure.

Power Control Subsystem: This subsystem will manage power to load devices to improve system operational longevity and performance. Through the use of an inverter and various power conversion circuits, this subsystem will ensure loads are powered throughout the system. Through the use of switches and sensors, outlets will be automatically turned on or off based on the mode of operation.

Camera Module: This subsystem will manage power of the camera and the transfer of camera video footage. The camera will be triggered by a PIR motion sensor. Once triggered the camera will go from a deep-sleep low voltage mode to an active surveillance mode. A video feed of images will be captured, stored local on an SD card. Near-real time video footage on the SD card will be transferred to the microprocessor via the network for image processing.

Microprocessor and Sensors: This subsystem is responsible for analyzing the sensor data and camera data. Through the use of a microprocessor near real-time video footage can be analyzed for threats. A lightweight classification model, will process the frames of the video data locally on the microprocessors. The model will look for the following security threats: Vandalism, Loitering, and Abnormal or Unsafe Movement. If a threat is detected, an app alert will be sent out and the LED will increase in brightness. The microprocessor will also receive sensor data about the camera, LED, and overall electrical metrics of the system. The sensors will be broken into three modules: Weather Sensor Module, Electrical Sensor Module, and Security Detection Sensor Module. These sensors will determine modes of operation.

Network: This subsystem will be used as the main method of communication between the camera, microprocessor and the app. This network will have WIFI connectivity, to allow the SolarEye Security System App administrator to monitor remotely, and view recent video footage if a threat has been detected. The network will be encrypted to secure sensitivity video footage of the area of interest.

SolarEye Security System App: This subsystem will be the main interface for users of the playground. Users of the app will be provided near real-time notifications of the park regarding safety. The application will also have administrator access, to allow the owner or operator of the playground to send manual notifications to users, remotely live-stream the play area, and manual control of non-camera load devices.

### 3.4. Modes of Operations

The SolarEye Security System will have three modes of operation.
The first main mode of operation is the daytime surveillance mode. This mode of operation will have all loads to be at full power. In this mode, an active live feed of the playground will be accessible by the administrator of the SolarEye Application.
The second mode of operation is the nighttime surveillance mode This mode of operation will only have the LED and camera load active. The camera load will be in a low-voltage sleep state that will be activated by a PIR sensor. Event history will be able to be accessed by the app admin when the camera is activated.
The third mode of operation is the low-power mode. This mode of operation will be activated by either the weather sensors or systems electrical sensors. In this mode, all the load devices will be off except for the LED. When this mode of operation is enabled the administrator will be notified to check the system or unsafe weather has been detected at the playground. The users will also be notified that either the security system is down, or unsafe weather has been detected. In both cases the user will be informed to not go to the park until either events are resolved.

### 3.5. Users

This system is designed to assist in the security of local play areas found in parks, playgrounds and schools. These areas may not have security guards or are not in proximity to a power system, thus this system can allow these areas to be used safely. Due to the nature of the system, multiple system units could be used in conjunction with an external network to protect larger playgrounds and parks.

### 3.6. Support

Support for the SolarEye Security System will be provided by the SolarEye Security App. The app will provide an overview of the types of load devices, the meaning of the different modes of operation, and what the LEDs' different brightness mean. Further tutorials on system alerts and a user forum will be provided for added user support.

## 4. Scenario(s)

### 4.1. After Hours Vandalism/Trespassing

Implementing a security system in parks and playgrounds can significantly enhance safety by deterring vandalism and preventing illegal activities. The surveillance system, paired with motion detection, not only alerts security teams when needed but also serves as a visible deterrent. This proactive approach ensures the space remains a welcoming and safe environment for families and children while discouraging trespassers from unlawful behavior.

### 4.2. Night-time Accessibility for Certain Parks

If the security system were to be used for a basketball park, the LED lights can be of assistance to the park people. They also can charge up their devices making sure they are in a safe area with their phone. Communities would benefit from this and more people would be able to access the basketball park with less worry.

### 4.3. Kidnapping from a Park

If there was an incident involving a child being taken, then the security system will be able to capture the events and be able to show the video of the events. This would better help authorities in finding the suspect and give a jumpstart to the investigation.

## 5. Analysis

### 5.1. Summary of Proposed Improvements

- The system will run entirely on solar energy, making it self-sufficient.
- Motion sensors will cause the camera to turn on, stopping the system from continuously recording, using up battery life, and wasting energy on the video processor.
- The system will operate according to a preset schedule and won't need user intervention for maintenance.
- The system will have three different modes, low, normal, and weather. Each mode will maintain the system energy as a predetermined schedule.
- The system will capture all videos and pictures on a SD card and will notify the app.
- The system will notify the app of battery life.
- System will also notify the app of suspicious activity.
- Deterrence by LED light, such as the light will shine brighter than normal for suspicious activity.

### 5.2. Disadvantages and Limitations

- It is ideal to position the camera unit high to reduce the risk of weather damage or vandalism.
- The system can lose power if the weather tends to be bad for multiple days on end.
- The camera range is limited due to budget constraints and power consumption.
- The camera system is in a fixed position which allows for blindspots.

### 5.3. Alternatives

- No security system but signs as deterrents to keep playgrounds safe.
- Night time security guards to keep watch of any illegal activities.
- Connection between the camera and the app could be facilitated through a WiFi system with audio and light deterrents.
- The whole security system can be powered through power lines instead of solar panels to ensure steady power to the system.

### 5.4. Impact

- Environmental Impact - The security system is solar powered making it a self-sustaining system using a clean energy source.
- Societal Impact - Access to technology is better because having a charging station can help underserved communities. This system can also help with inclusivity within the community by making playgrounds safer for children to visit.
- Ethical Impact - Video history of the park can be stolen or tampered with which can lead to issues if an incident were to occur.
- Mental Impact - Parents can have a peace of mind knowing their children are at a safe playground with a charging station if they have a device.

# SolarEye Security System

## Alex Allahar Victor Igbokwe Jackson Kitchel Zayan Prasla

## FUNCTIONAL SYSTEM REQUIREMENTS

FUNCTIONAL SYSTEM REQUIREMENTS

FOR

## SolarEye Security System

PREPARED BY:

_____________________________
Author | Date

APPROVED BY:

_____________________________
Alex Allahar | Date

_____________________________
John Lusher, P.E. | Date

_____________________________
T/A | Date

Change Record

Rev . | Date | Originator | Approvals | Description
1 | 09/26/2024 | SolarEye Security System | | Draft Release
2 | 10/04/2024 | SolarEye Security System | | Diagrams Modified

Table of Contents
List of Tables | 5
List of Figures | 6
1. Introduction (https://docs.google.com/document/d/1msWzTAFhRjYMLn1X-83ekmafh9Hv_fVg/edit#heading=h.tyjcwt) | 7
2. Applicable and Reference Documents | 8
3. Requirements | 10
4. Support Requirements | 13
Appendix A Acronyms and Abbreviations | 14

List of Tables
Table1:SubsystemAssignments | 7
Table2:ReferenceDocuments | 8
Table 3: Application Documents | 8

List of Figures

## 1. Introduction

### 1.1 Purpose and Scope

The Solar Playground security system, powered by the Solareye Security System, is designed to ensure the safety and well-being of children in parks and playgrounds through automated surveillance technology. Rather than relying on security officers or bystanders, this eco-friendly system actively monitors play areas using cameras, LED lighting, and charging outlets. Motion-triggered LED lights provide enhanced visibility at night, deterring potential wrongdoers by drawing attention to the camera. The app can be used for sending alerts and providing images directly to users’ mobile devices, while also offering manual controls and event history. In addition, the system is powered by solar energy, making it self-sustaining and independent from the grid. By eliminating the need for continuous monitoring by personnel or nightly patrols, Solareye Security System provides both active and passive surveillance, reducing power consumption and operational costs. The system also includes charging outlets for parents and guardians, ensuring they have access to fully charged devices in case of emergencies. Overall, the Solar Playground system offers a modern, cost-effective solution that enhances security while creating a safer and more inclusive environment for public spaces.


Figure 1: SolarEye Security System Concept Image

### 1.2 Responsibility and Change Authority

The team leader, Alex Allahar, will have the responsibility of making sure the requirements are met. The requirements can only be changed by the team leader and Dr. Wonhyeok Jang.

Subsystem | Responsibility
Solar Power and Battery | Jackson Kitchel
Power Distribution/Load Management | Victor Igbokwe
Camera, Micronctonroller, and Sensors | Alex Allahar
Network and App | Zayan Prasla
Table 1: Subsystems Assignments

## 2. Applicable and Reference Documents

### 2.1 Applicable Documents

The following documents, of the exact issue and revision shown, form a part of this specification to the extent specified herein.

Document Number | Revision/Release Date | Document Title
IPC-A-610 J | Revision J - 4/4/2024 | Acceptability for Electronic Assemblies
802.11 | 1/23/1997 | Local Area Network(LAN) Technical Standards
1910.305(a) | 3/31/2004 | Wiring Methods, components and equipment
ANSCI C119.6 | 6/29/2018 | American National Standard for Electric Connectors -Non-Sealed, Multiport Connector Systems Rated 600 Volts or Less for Aluminum and Copper Conductors

### 2.2 Reference Documents

The following documents are reference documents utilized in the development of this specification. These documents do not form a part of this specification and are not controlled by their reference herein.

Document Number | Revision/Release Date | Document Title
IEC 61730 | 09/13/2023 | Photovoltaic (PV) module safety qualification
NFPA 855 | 8/25/2023 | Standard for the Installation of Stationary Energy Storage Systems
UL-1642-Fifth Edition | 3/13/2012 | Standard for Lithium Batteries

### 2.3 Order of Precedence

In the event of a conflict between the text of this specification and an applicable document cited herein, the text of this specification takes precedence without any exceptions.

All specifications, standards, exhibits, drawings or other documents that are invoked as “applicable” in this specification are incorporated as cited. All documents that are referred to within an applicable report are considered to be for guidance and information only, except ICDs that have their relevant documents considered to be incorporated as cited.

## 3. Requirements

### 3.1. System Definition

The SolarEye Security System is a cutting-edge, sustainable solution designed to enhance security in local neighborhood playgrounds. It combines both active and passive surveillance methods to monitor play areas effectively. Using automated camera detection and advanced image processing, the system continuously scans for irregularities and immediately alerts administrators and users through the SolarEye app. The app provides access to event history and sends real-time notifications, ensuring timely responses.
The system operates through an integrated network, gathering image data and issuing notifications to users. Its responsive LED lighting system, which brightens when motion is detected at night, serves both as a deterrent to potential intruders and a safety feature for park visitors. Additionally, the system powers device charging stations, allowing users, such as parents and guardians, to keep their phones charged for emergency use. Fully self-sustaining, the SolarEye Security System removes the need for human oversight while offering a reliable security presence to safeguard playgrounds in parks and schools.


Figure 2: SolarEye Security System Block Diagram

The SolarEye Security System system starts with a solar generation subsystem. The solar panel charges the 12V battery. This subsystem is connected directly to the power distribution subsystem. The power distribution subsystem provides the correct voltage and current to the system load devices. The load devices in the system are the IP camera, Raspberry PI, LED, USB-A and USB-C. This subsystem should automatically change power sent to load devices depending on the mode of operation. This subsystem leads into the camera, microcontroller and sensor subsystem. This subsystem is responsible for providing surveillance and capturing information about the playground area of interest. Using a motion sensor to trigger a camera, the video footage will be processed and classified using the Raspberry PI. The Raspberry PI will brighter the LED, and send app alerts via the network. The outputs of the subsystem go to the final subsystem network and App. This subsystem will transmit data from the Raspberry PI and mobile app to all near-real time update about playground security.


Figure 3: SolarEye Security System Camera Surveillance Flowchart

When motion is detected using the PIR Sensor the camera will record a small video stream of footage. This footage will be sent to the Raspberry PI via a wire. Locally, the frames of video are extracted into images. These images are pre processed and converted into a lower resolution. These new images are then filtered and sent to an image classification inference model, to determine if any abnormal motion or object are detected. Depending on the output of this model, the system's LED will increase in brightness to deter the action detected by the camera. The outputs of the model will also send a JSON output that the network will transmit and push to app alerts to users of the SolarEye Security App.

### 3.2. Characteristics

### 3.2.1. Functional / Performance Requirements

### 3.2.1.1. Active Deterrence

The security system will use various LED light levels to act as active deterrence in the playground.
Rationale: The system must be able to provide active security for users at the playground that may not have access to the app.

### 3.2.1.2. Solar Charging Time (6 hours)

The solar charging system shall provide a full charge to the battery in 6 hours assuming direct sunlight.

### 3.2.1.3. Time to App Alert

Assuming the Wi-Fi and power source is uninterrupted, it should take no longer than 5 minutes to alert the app.

### 3.2.1.4. Camera Node FOV

The camera node shall be able to monitor 250-300 foot area with a 120 degree radius.

### 3.2.1.5. Image Classification Inference Accuracy

The Image Classification inference accuracy should be around 55-65%.

### 3.2.1.6. Motion Detection accuracy

The motion detection accuracy should be around 65-75%.

### 3.2.1.7. Input Voltage Level

The input voltage level for the Search and Rescue System shall be +12 VDC.

Rationale: The battery will output +12V VDC into the power distribution circuit which will convert the power for each load.

### 3.2.1.8. Wiring

The solar security system shall follow the guidelines set forth in the National electrical code regarding electrical wiring.

### 3.2.1.9. Thermal

The solar security system may be able to function properly in an environment with temperatures ranging 20°F to 110°F

Rationale: The temperature in College station can reach up to 110°F, and the minimum temperature can reach 20°F. Our range ensures the system can properly function in varying climates year round.

### 3.2.1.10. Connectors

The solar security system shall follow the American National Standard for Electrical Connectors ANSI C119.6-2011.

### 3.2.1.11. Battery Operating Time

The system should be functional on battery power for 7-8 hours.

### 3.2.2. Physical Characteristics

### 3.2.2.1. System Area

The system can provide surveillance over a 250-300 sq.ft provided that the system's camera is installed 6-7 feet in the air and 8-9 feet from the edge of the playground.

### 3.2.2.2. Installation

Installation manual will be provided to the client.

### 3.2.2.3. Mounting

Information about mounting will be provided in the Solareye Security System ICD.

### 3.2.2.4. Water Resistance

The system shall be enclosed in a water resistant case to protect electrical components.

### 3.2.2.5. Field of View

The field of view of the camera should be 120 degrees.

### 3.2.3. Electrical Characteristics

### 3.2.3.1. Outputs

### 3.2.3.2. Data Output

The SolarEye Security System will have an android application for users to view alerts and should be able to view images.

Rationale: The SolarEye Security System should be readily available to the user through an android application.

### 3.2.3.3. Raw Video Output

The SolarEye Security System should have an internal SD card to store video footage of daily events.
Rationale: Store longer videos on the SD card.

### 3.2.4. Environmental Requirements

The SolarEye Security System shall be designed to withstand and operate in the environments and laboratory tests specified in the following section.

### 3.2.4.1. Pressure (Altitude)

The SolarEye Security System should be able to function properly at altitudes ranging from sea level to 450 feet above sea level.

### 3.2.4.2. Thermal

The SolarEye Security System should be able to function properly in an environment with temperatures ranging from 20°F to 120°F.

### 3.2.4.3. Rain

The SolarEye Security System should be functional as the power supply should store electricity use while there is no sunlight during rain.

### 3.2.4.4. Humidity

The SolarEye Security System may be able to function properly in an environment with relative humidity ranging from 0% to 100%.

### 3.2.5. Failure Propagation

The Solareye Security System should not allow any faults

## 4. Support Requirements

### 4.1.1 Android Phone or Tablet with Internet Connection

In order to access the camera and LED controls as designed, the user must have access to an Android Phone or Tablet with internet connection to view the application.

### 4.1.2 Shade Free Area

To maintain a steady power supply the system must be kept out in the sun, away from shade for the solar panel to convert sunlight into electricity.

## Appendix A: Acronyms and Abbreviations

LED | Light Emitting Diode
PIR | Passive Infrared
FOV | Field of View
USB | Universal Serial Bus

# SolarEye Security System

# Alex Allahar Victor Igbokwe Jackson Kitchel Zayan Prasla

## INTERFACE CONTROL DOCUMENT

INTERFACE CONTROL DOCUMENT

FOR

## SolarEye Security System

PREPARED BY:

_____________________________
Author | Date

APPROVED BY:

_____________________________
Alex Allahar | Date

_____________________________
John Lusher II, P.E. | Date

_____________________________
T/A | Date

Change Record

Rev . | Date | Originator | Approvals | Description
1 | 09/24/24 | SolarEye Security System | | Draft Release
2 | 10/05/24 | Victor Igbokwe | | LED Hideaway Strobe Lights Removed

Table of Contents

List of Tables
Table 1: Solar Generation Weight
Table 2: Camera and Sensor Unit Weight Table 3: Load Devices Weight
Table 4: Solar Generation Unit Dimensions Table 5: Camera and Sensor Dimensions Table 6: Load Devices Dimensions
Table 7: Maximum Voltage and Current Levels Table 8: Stand-by Voltage and Current

List of Figures
Figure 1: Electrical Interface Diagram

## 1. Overview

This document provides the details for the SolarEye Security System. It will list the inputs and outputs of the system and detail how the system manages them. The parts that are intended to be used to design the system are mentioned in this section of the document. Attributes of the parts such as physical, electrical, and thermal, communication and device interface protocols are described.

## 2. References and Definitions

### 2.1 References

Refer to section 2.2 of the Functional System Requirements document.

### 2.2 Definitions

oz | ounces
m | meters
in | inches
mA | Milliamp
mW | Milliwatt
MHz | Megahertz (1,000,000 Hz)
TBD | To Be Determined

## 3. Physical Interface

### 3.1 Weight

### 3.1.1 Solar Generation Weight

Component | Weight | Number of Items | Total Weight
12.8V 50Ah 640Wh LiFePO4 Lithium Battery | ~20lbs (TBD) | 1 | ~20lbs (TBD)
Charging Circuit PCB | TBD | 1 | TBD
75W-100W Solar Panel | TBD | 1 | TBD

### 3.1.2 Camera and Sensor Unit Weight

Component | Weight | Number of Items | Total Weight
Raspberry Pi 4 B | 0.76 oz | 1 | 0.76 oz
Ansice IP Camera | 15.9 oz | 1 | 15.9 oz
DaierTek Battery Voltage Meter | 1.76 oz | 1 | 1.76 oz
Raspberry Pi 15W USB-C Power Supply | 5.13 oz | 1 | 5.13 oz

### 3.1.3 Load Devices Weight

Component | Weight | Number of Items | Total Weight
Buck Converter PCB | TBD | 1 | TBD
USB Charging Ports | TBD | 3 | TBD

### 3.2 Dimensions

### 3.2.1 Dimension of Solar Generation

Component | Length | Width | Height
12.8V 50Ah 640Wh LiFePO4 Lithium Battery | 7.68 in | 6.42 in | 6.61 in
Charging Circuit PCB | TBD | TBD | TBD
75W-100W Solar Panel | TBD | TBD | TBD

### 3.2.2 Dimension of Load Devices

Component | Length | Width | Height
Buck Converter PCB | TBD | TBD | TBD

### 3.2.3 Dimension of Camera and Sensors Unit

Component | Length | Width | Height
Raspberry Pi 4 B | 3.37 in | 2.22 in | 0.67 in
Ansice IP Camera | 8.54 in | 4.41in | 3.23 in
DaierTek Battery Voltage Meter | 6.57 in | 4.29 in | 1.06 in
Raspberry Pi 15W USB-C Power Supply | 1.5 m | TBD | TBD

### 3.3 Mounting Locations

The system is meant to be mounted on a pole minimum 6-7 feet above the ground. The camera field of view is 120 which should cover a minimum of 250 sq ft. The system must be clear of any shade/coverings so the solar panel can successfully charge the battery and power the system, but also accessible for the charging station.

## 4. Thermal Interface

The Raspberry Pi 4 B will use a heat sink that has a cold wall. Since the Raspberry Pi 4 B will be responsible for analyzing video footage, hosting the database, collecting data on the sensors, and transmitting data to the users of the mobile app, a heat sink will be needed to prevent overheating. Due to the need of the security system to provide near real-time updates on the park's security, overheating could lead to a decrease in efficiency of the Raspberry Pi and thus a decrease in security of the playground.

### 4.1 Battery Cooling

The battery will be enclosed in a well-ventilated housing, ensuring efficient dissipation of excess heat.

## 5. Electrical Interface

Figure 1: Electrical Interface Diagram

### 5.1 Primary Input Power

The Primary input power will be a 12 volt Lithium battery, that will be charged by a 90 Watt solar panel.

### 5.2 Voltage and Current Values

### 5.2.1 Maximum Values

Component | Voltage(V) | Current(A) | Power(W)
USB Charging | 5 | 1 | 5

Ports

LED Hideaway Strobe Lights | TBD | 1 | TBD
Raspberry Pi 4 | TBD | TBD | TBD
Sensors | TBD | TBD | TBD
Camera | 12 | 2 | 24
Battery | 12.8V | ≤50A | 640Wh
Solar Panel | TBD | TBD | 90W

### 5.3 Signal Interfaces

The camera and the microcontroller are connected via wired connection. The microcontroller has a general network adapter which includes WiFi Network.

### 5.4 User Control Interface

The user interface is a web application on Android devices only. The application will connect to the main control unit or the main microprocessor for the system. The user interface should present battery charging statistics, predict charge patterns, and predict when the battery life ends. There should be AI suggestions/reminders to help the user check on the system. There will be a secure login to keep the application in safe hands.

## 6. Communications / Device Interface Protocols

### 6.1 Wireless Communications (WiFi)

The microcontroller has a built-in WiFi module using IEEE 802.11 g/b/n standards. This connection will be used to send alerts to the user application using serial communication.

### 6.2 Host Device

The host device will be the Raspberry Pi 4 B, which will host its own server/database.

### 6.3 Device Peripheral Interface

The Camera has a built-in PIR Sensor to detect motion. Once triggered the camera will record and transmit video footage to the Raspberry Pi to begin the security system process.

# SolarEye Security System

# Alex Allahar Victor Igbokwe Jackson Kitchel Zayan Prasla

## EXECUTION PLAN

# SolarEye Security System

# Alex Allahar Victor Igbokwe Jackson Kitchel Zayan Prasla

## VALIDATION PLAN

# SolarEye Security System

# Alex Allahar Victor Igbokwe Jackson Kitchel Zayan Prasla

## SUBSYSTEM REPORTS

SUBSYSTEMS REPORTS

FOR

## SolarEye Security System

PREPARED BY:

_____________________________
Author | Date

APPROVED BY:

_____________________________
Alex Allahar | Date

_____________________________
John Lusher II, P.E. | Date

_____________________________
T/A | Date

Change Record

Rev . | Date | Originator | Approvals | Description
- | 09/24/24 | SolarEye Security System | | Draft Release

Table of Contents

List of Figures | 46
List of Tables | 47

### 1. Introduction | 48 2. Solar Generation Subsystem Report | 48

2.1. Subsystem Introduction | 48
2.2. Subsystem Design | 48
2.3 Subsystem Details | 49
2.2.1.Maximum Power Point Tracking | 48
2.2.2.Current Sensors | 49
2.3.Subsystem Conclusion | 50

### 3. Power Subsystem Report | 50

3.1. Subsystem Introduction | 50
3.2. Subsystem Details | 51
3.2.1 Step Down Buck Converter | 51
3.2.2 Step Up Boost Converter | 52
3.3. Subsystem Conclusion | 53

### 4. Microprocessor Subsystem Report | 53

4.1. Subsystem Introduction | 53
4.2. Subsystem Details | 54
4.2.1 PIR Sensor | 54
4.2.2 Camera | 54
4.2.3 Firebase Database | 56
4.3. Subsystem Conclusion | 56

### 5. App Subsystem Report | 56

5.1. Android Application and Database Introduction | 56
5.2. Android Application Details | 56
5.2.1. User Login Security | 57
5.2.2. Home/Settings Page | 57
5.2.3 Event History | 57
5.3. Android Application Validations | 58
5.4. Android Application Conclusion | 60

List of Figures

Figure 8: Login page showing email verification is needed, Create an Account page, email

List of Tables

## 1. Introduction

The SolarEye Security System autonomously monitors playground and park security by collecting data from sensor and camera modules, centralizing it, and uploading it to an online platform accessible via a mobile app. The system is divided into the following subsystems: Solar Generation, Power, Microprocessor, and data SolarEye Security App. These subsystems were specified in the Conops, FSR, and ICD. These subsystems are expanded upon below.

## 2.Solar Generation Subsystem Report- Jackson Kitchel

### 2.1 Subsystem Introduction

The Solar power generation subsystem serves as the central power source within the project. The subsystem is responsible for the solar panel, charging circuit PCB and supplying power to the 12-volt battery. The 100W solar panel is connected directly to the charging circuit PCB which regulates the power and supplies the 12-volt battery with a safe and efficient supply voltage. The power from the solar panel is used efficiently by using a Maximum Power Point Tracking (MPPT) IC chip. Additionally, the voltage and current supply from the solar panel as well as the battery are monitored by the charging circuit using current sensors and voltage sensors in combination with an ADC. These data points are then output by the PCB to be read and processed by the Raspberry Pi 4B.

### 2.2 Subsystem Design

The charging circuit PCB was designed initially using LTspice in which the initial iteration and testing were done. After thorough validation of the design, hardware and specifications were selected and the circuit was then designed in Altium. After careful redesign and consolidation, the final PCB layout can be seen below. Following the final iteration of the Altium PCB design, the parts and PCB were ordered. Lastly, the PCB had to be soldered and tested before being integrated into the system with the other subsystems.


Figure 1: Solar Charging PCB Layout


Figure 2: Soldered Charging Circuit

### 2.3 Subsystem Details

The charging circuit uses several components and IC chips to properly regulate the power supply. The first is the BQ24650, which serves as the Maximum Power Point Tracking (MPPT) aspect of the circuit. This ensures the circuit is able to provide the battery with maximum power, depending on the input voltage of the solar panel. This will change throughout the day contingent upon the sunlight and weather conditions. Furthermore, the circuit incorporates 2 ACS723 current sensor IC chips to monitor the current and voltage at the input and output of the circuit. Details of these components and schematic setup are as follows:

### 2.3.1 Maximum Power Point Tracking

The BQ24650 serves many purposes in the circuit with the main function being the maximum power point tracking. This allows the battery to be charged at the most efficient rate, while minimizing power loss. To achieve this, the IC chip regulates the charge voltage of the battery based upon the input voltage of the solar panel. Furthermore, the BQ24650 facilitates the high/low cutoff for the charging circuit. In this case, the charging circuit will cut off voltage to the battery when the battery exceeds 15V (cut off voltage). It will also ensure that the circuit begins charging the battery when the battery falls to 12.4V (cut on voltage). These measures will ensure that the battery is never overcharged, while also maintaining charge within the battery. Furthermore, the BQ24650 incorporates temperature protection via a thermistor. This ensures that the battery will never overheat while being charged in order to prevent damages and hazards. The schematic setup of the BQ24650 can be seen below along with its efficiency curve:


Figure 3: Solar Power Charging Circuit Schematic

Figure 4: Solar Power Charging Circuit Efficiency vs Output Voltage

### 2.3.2 Current Sensors

The charging circuit incorporates two ACS723 current sensor IC chips. These are placed at the input from the solar panel, and the output to the battery as seen in the schematic above. The current sensors allow for voltage and current at these two nodes to be recorded and sent to the Raspberry Pi 4B via the terminal connections J5A/B and J6A/B as seen in the schematic setup below. These readings will then be sent from the microcontroller to the app to allow the user to be able to monitor the charging status and battery voltage. This data can be used to monitor efficiency, as well as cue modes such as low battery mode etc. to activate. The schematic setup of these current sensors can be seen below:


Figure 5: Current Sensor Schematic

### 2.4 Subsystem Validation

Solar Generation Subsystem was tested through a series of hardware tests to confirm that all units functioned as anticipated. System behavior was tracked throughout the day under conditions of changing solar, with solar irradiance, charging current, and battery voltage recorded. The data are shown in the table below. The charging circuit closely tracked the maximum power point as irradiance changed. As shown, charging current was at its maximum of 0.83 A under full sun at noon, 12:00 PM, and provided maximum charge power of 10.79 W. As solar irradiance decreased during the afternoon, charging current correspondingly decreased as well, highlighting good MPPT functionality by the BQ24650 IC. This can be seen in Figure 6 below. Battery voltage increased steadily during charging, reaching a nearly full charge (13.6 V) by mid-day. The circuit then went into a trickle charge mode, where battery voltage was maintained without overcharging. Cut-on voltage (~12.4 V) and cut-off voltage (~15 V) were set during testing and confirmed the operation of the BQ24650 charge control features. ACS723 current sensors were also tested by comparing real-time data output to a calibrated multimeter. Solar panel and battery output current was within ±5% tolerance, confirming sensor accuracy and reliable ADC sampling from the Raspberry Pi 4B. This was tested at different times of the day comparing the voltage and current readings from the MCU to the real measurements from the multimeter. The results were recorded in Figures 8 and
9. Finally, thermal protection functionality was confirmed by heating the battery environment. The thermistor correctly triggered a charge shutdown upon the onset of elevated temperatures, demonstrating system safety. Overall, the subsystem testing verified that the Solar Generation Subsystem provides stable, efficient, and safe charging to the 12V battery under various environmental conditions.

Time
of Day

Solar
Irradiance
(%)

Charging
Current (A)

Battery
Voltage (V)

Delta
V (V)

Charge
Power (W)

Notes

6:00
AM
10% | 0.08 | 11.8 | | 0.944 | Early sun, low output

8:00
AM
40% | 0.33 | 12.1 | 0.3 | 3.993 | Gaining sun

10:00
AM
70% | 0.58 | 12.5 | 0.4 | 7.25 | Good charge

12:00
PM
100% | 0.83 | 13 | 0.5 | 10.79 | Peak solar output

2:00
PM
90% | 0.75 | 13.4 | 0.4 | 10.05 | Near full charge

4:00
PM
50% | 0.42 | 13.6 | 0.2 | 5.712 | Battery nearly topped off

6:00
PM
20% | 0.08 | 13.6 | 0 | 1.088 | Trickle charge only

8:00
PM
0% | 0 | 13.4 | -0.2 | 0 | No sun, battery idle

Figure 6: Charging Circuit MPPT Testing


Figure 7: Simulated Solar Inputs vs Charging Voltage

Time Measurement
Point

Multimeter
Reading

MCU
Reading

Deviation
(%)

Notes

8:00 AM Solar Panel
Input Voltage
14.8 | 14.6 | -1.35 | Low morning output

Solar Panel
Input Current
0.34 | 0.33 | -2.94

Battery Output
Voltage
12.1 | 12 | -0.83 | Beginning charge

Battery Output
Current
0.32 | 0.31 | -3.12

12:00
PM

Solar Panel
Input Voltage
18.1 | 18 | -0.55 | Peak irradiance

Solar Panel
Input Current
0.85 | 0.83 | -2.35

Battery Output
Voltage
13 | 12.9 | -0.77 | Strong charging

Battery Output
Current
0.82 | 0.79 | -3.66
4:00 PM | Solar Panel
Input Voltage
15.6 | 15.4 | -1.28 | Afternoon sun declining

Solar Panel
Input Current
0.44 | 0.42 | -4.55

Battery Output
Voltage
13.6 | 13.5 | -0.74 | Nearly full charge

Battery Output
Current
0.41 | 0.39 | -4.88

Figure 8: Voltage and Current Sensors MCU vs Multimeter Values

Figure 9: Multimeter vs MCU Readings Line Chart

### 2.5 Subsystem Conclusion

In conclusion, the Solar Charging Circuit subsystem is designed to provide safe and efficient charging from the 100W solar panel to the 12-volt battery. This is critical as the entirety of this project relies on a reliable power source. The circuit achieves this by incorporating maximum power point tracking, automatic cut on/off, high temperature protections, and current and voltage readings at the input and output to the MCU. These key components make it possible to operate and charge the battery independently and safely.

## 3. Power Subsystem Report- Victor Igbokwe

### 3.1 Subsystem Introduction

The Power Distribution System plays a critical role in delivering stable and efficient electrical power throughout the project. A 12-volt battery serves as the primary energy source, directly powering 12-volt devices such as the camera and LED lights. To supply the Raspberry Pi, a dedicated Buck Converter PCB steps down the 12-volt input to a regulated 5-volt output, ensuring safe and reliable operation of the microprocessor unit (MPU). Additionally, a Relay Control Module PCB is integrated into the system, acting as an interface that allows the 5-volt Raspberry Pi to control 12-volt load devices. This design enables seamless communication and control across different voltage domains, resulting in a robust, versatile, and highly coordinated power distribution network tailored to the project's needs.

### 3.2 Subsystem Details

### 3.2.1 Buck Converter PCB

The Buck Converter PCB receives 12V input directly from the main battery and steps it down to a stable 5V output to supply power to the Raspberry Pi.
Key components of the buck converter include:
- A high-efficiency DC-DC regulator IC
- Input and output filter capacitors to minimize voltage ripple
- An inductor to regulate current during switching
- Protection circuitry including input reverse polarity protection and output overcurrent protection
The Buck Converter is designed to deliver sufficient current for the Raspberry Pi and its peripherals while maintaining low noise and stable voltage under load conditions.


Figure x: Buck Converter Altium Circuit Schematic


Figure x: Buck Converter

### 3.2.2 Relay Control Module PCB

The Relay Control Module PCB enables the Raspberry Pi to control 12V load devices such as LED lights and cameras. It uses N-Channel MOSFETs as high-speed solid-state switches.
Key features include:
- Low-side switching topology
- Pull-down resistors on each MOSFET gate to prevent accidental activation
- Logic-level MOSFETs compatible with 3.3V to 5V GPIO signals
- Separate power paths for control (5V) and load (12V) circuits for electrical isolation and safety
When a GPIO pin outputs a HIGH signal, the corresponding MOSFET turns on, connecting the load to ground and allowing current to flow from the 12V source through the device..


Figure x: Relay Control Module Altium Circuit Schematic

Figure x: Relay Control Module PCB

### 3.3 Subsystem Validation

The validation process of the power subsystem ensured the DC-DC converter and the Relay Control module PCB meet the operational and design requirements.

Validation criteria (Buck Converter) include:
- Voltage regulation
- Efficiency
- Load Testing
Validation criteria( Relay Control Module) include:
- Load Testing
- Voltage Regulation
- Mosfet Switching
- Fault tolerance

### 3.3.1 Buck Converter Performance

Test Equipment:
- Digital Multimeter (for voltage and current measurement)
- DC-Electronic Load (for applying variable current loads)


Figure x: Buck Voltage regulation

The graph above shows the output voltage of the buck converter as the input voltage was varied from 10V to 13V. Across the tested range, the output remained stable between 5.09V and 5.06V, demonstrating excellent voltage regulation performance. The slight decrease in output voltage with increasing input voltage was minimal and well within acceptable limits, confirming the converter’s ability to maintain a consistent 5V output under varying supply conditions.


Figure x: Buck Load Regulation

Output Current (A) | Output Voltage (V) | Voltage Drop (V) | Voltage Drop (%)
0.00 | 5.082 | 0.000 | 0.00%
0.10 | 5.080 | 0.002 | 0.04%
0.20 | 5.075 | 0.007 | 0.14%
0.30 | 5.072 | 0.010 | 0.20%
0.40 | 5.070 | 0.012 | 0.24%
0.50 | 5.068 | 0.014 | 0.28%
0.75 | 5.066 | 0.016 | 0.31%
1.00 | 5.060 | 0.022 | 0.43%
1.25 | 5.040 | 0.042 | 0.83%
1.50 | 5.020 | 0.062 | 1.22%
1.60 | 5.015 | 0.067 | 1.32%
1.75 | 5.005 | 0.077 | 1.52%
2.00 | 4.980 | 0.102 | 2.01%
Figure x: Voltage Drop Under Load.

The voltage drop testing confirms that the converter performs well within acceptable limits for the intended application, especially considering that the load is unlikely to exceed 2A during normal operation.


Figure x: Power Consumption Validation. The graph above illustrates the measured power consumption for different system configurations compared against their respective power limits. The Fans subsystem exceeded the specified 5W limit, recording a power draw of 8.8W, resulting in a failed validation for this case. However, the Raspberry Pi subsystem consistently passed under all tested modes — low power (9.4W), default (10.75W), and live streaming (18.25W) — remaining well below the 20W maximum limit. These results validate that the Raspberry Pi can operate safely within the system’s power constraints under both idle and high-demand conditions. The tests were conducted using a digital multimeter and inline power meter during normal operation and stress conditions to ensure reliable and repeatable measurements.

### 3.3.2 Relay Control Module Performance

Test Equipment:
- Digital Multimeter (for voltage and current measurement)
- DC-Electronic Load (for applying variable current loads)

Figure x: Relay Control Module Load regulation

Output Current (A) | Output Voltage (V) | Voltage Drop (V) | Voltage Drop (%)
0.00 | 12.02 | 0.00 | 0.00%
0.10 | 12.00 | 0.02 | 0.17%
0.20 | 12.00 | 0.02 | 0.17%
0.30 | 11.99 | 0.03 | 0.25%
0.40 | 11.98 | 0.04 | 0.33%
0.50 | 11.96 | 0.06 | 0.50%
0.60 | 11.96 | 0.06 | 0.50%
0.70 | 11.94 | 0.08 | 0.67%
0.80 | 11.93 | 0.09 | 0.75%
0.90 | 11.91 | 0.11 | 0.92%
1.00 | 11.90 | 0.12 | 1.00%
Figure x: RCM Voltage Drop Under Load.

The Relay Control Module demonstrated excellent load regulation performance across the 0–1A output current range. The maximum voltage drop observed was approximately 1.00%, with a gradual and controlled decrease in output voltage as current increased. Overall, the module maintained stable output under varying load conditions, confirming its reliability for controlling 12V devices.


Figure x: Relay Control Module Technical block diagram

The Relay Control Module utilizes N-Channel MOSFETs as solid-state switches to control 12V load devices. Switching occurs when a logic-level voltage (approximately 5V) from a Raspberry Pi GPIO pin is applied to the gate of the MOSFET. When the gate-to-source voltage (Vgs) exceeds the MOSFET’s threshold voltage (typically around 2–3V), the MOSFET enters saturation mode and conducts fully, allowing current to flow from the load through the MOSFET to ground. This behavior effectively closes the circuit and powers the connected load.

During validation, an oscilloscope was used to observe the gate-source voltage transitions. The switching was found to be clean and fast, with no significant ringing or oscillation, indicating a stable and well-designed gate drive circuit. The MOSFETs demonstrated a fast turn-on time (rise time < 1 µs) and turn-off time (fall time < 1 µs), ensuring responsive control of connected devices.


Figure x: Figure X: MOSFET Switching Times as a Function of Load Current

Additionally, pull-down resistors were incorporated on each gate to ensure that, in the absence of a GPIO control signal, the MOSFETs would reliably remain off. This prevents accidental activation of the loads due to floating gate voltages during system startup or when the Raspberry Pi is powered down.

### 3.3 Subsystem Conclusion

Comprehensive validation testing confirmed that both the Buck Converter PCB and the Relay Control Module PCB meet their performance specifications. The buck converter demonstrated excellent voltage regulation with a maximum voltage drop of only 2% across the 0–2A load range, and maintained a stable 5V output even as the input voltage varied. Ripple voltage remained low, and efficiency exceeded 85%, validating the design for reliable Raspberry Pi operation. The Relay Control Module, utilizing N-Channel MOSFETs, showed fast and clean switching behavior with Turn-On and Turn-Off times consistently below 120 nanoseconds across loads up to 2A. Voltage drop across the relay module under load remained minimal, with less than 1% regulation loss up to 1A. All thermal tests confirmed safe operating temperatures under maximum expected load conditions. Overall, the validation results confirm that the power distribution and control subsystem performs robustly, efficiently, and reliably, ensuring safe system operation under all normal and stress conditions.

## 4. Edge Processing Unit Subsystem Report - Alex Allahar

### 4.1 Subsystem Introduction

The purpose of this subsystem is to act as the system’s edge processing unit. It collects and processes data from sensors and the camera, and communicates this information to users through the SolarEye Security App. A Raspberry Pi microprocessor serves as the central link between the system’s physical components — such as the PIR sensor, ADC, camera, cooling fans, and LED — and the software components, including the cloud database and mobile app.

Beyond basic data collection, the microprocessor also controls key system functions. It manages video capture, cooling system activation, LED deterrence, and reads real-time battery and solar telemetry. It supports multiple operating modes — Low Power Mode, Motion Detection Mode, and Livestream Mode — adjusting system behavior automatically based on user settings or battery conditions to optimize performance and extend system runtime.

The subsystem connects directly to Firebase, enabling real-time event logging, video storage, system control updates, and secure remote access. Through this setup, users can receive instant motion notifications, monitor system health, access stored events, and control system features remotely, ensuring a flexible and reliable security solution.

### 4.2 Subsystem Details

The heart of the subsystem is a Raspberry Pi 4B. This microprocessor is currently connected to the PIR Sensor and Camera. Eventually, charging ports, LEDs, and a battery sensor will be controlled by the microprocessor via GPIO pins.

### 4.2.1 PIR Sensor

The PIR Sensor enables us to detect motion, based on infrared radiation. This reduces the PIR Sensor from detecting non-thermal movement such as trees or playground equipment moving. For the scope of this system a PIR Sensor that is functionally in mild outdoor conditions, energy-efficient and able to detect motion up to at least 16 ft away with an FOV of 120 degrees is required. The PIR Sensor selected to achieve this demand was a HC-SR501 PIR Sensor. It has a built-in voltage regulator that can run with anywhere from 4.5 to 20 volts, and a sensitivity that can be adjusted from 3 to 7 meters.

When testing the PIR Sensor range and FOV a range of 16ft was achieved and a FOV of 120 degrees was validated. After the delay between the PIR Sensor and when the database recorded the motion and time was measured. In order to provide near real-time security alerts to users of the SolarEye Security App, we need to achieve a sub 1 second delay from the event occurring and the cloud database. An average of 10 trials in which the PIR Sensor automatically listens for motion, uploads the data, and records the time taken locally on the microprocessor. The results from this are shown in the table below:

Trials | 1 | 2 | 3 | 4 | 5 | 6 | 7 | 8 | 9 | 10
Time(s); | 0.2039 | 0.0671 | 0.0609 | 0.0706 | 0.0632 | 0.0616 | 0.0632 | 0.0616 | 0.0625 | 0.0694
Table 1: Motion Detection Database Acknowledgement Delay

These values provided an average of 0.0784 seconds. Due to this microprocessor's ability to collect and communicate information from a sensor connected to the GPIO pins, the additional voltage sensor data will be handled by the microprocessor in the same fashion.

### 4.2.1 ADC

To determine the solar and battery statistics for the system an ADC-1115 was connected to the Solar Generation PCB voltage sensors and the MPU’s I2C pins. This allows the MPU to track the battery and solar panel in real time. This helps the system estimate battery life and monitor charging status.

The ADC reads four signals:

- Battery voltage (Channel A0)
- Battery current (Channel A1)
- Solar panel voltage (Channel A2)
- Solar panel current (Channel A3)

Since the battery and solar panel voltages are too high for the ADC to measure directly, voltage dividers are used to safely scale the voltages down. For the battery, a divider with a 21:1 ratio is used. For the solar panel, a 40:1 ratio is used. The system then multiplies the ADC reading by the divider ratio to get the real voltage.

Battery life is estimated by comparing the battery voltage to a full-charge value (12.8V). The system calculates the State of Charge (SOC) as a percentage of this full value. If the voltage is above 13.0V, the battery is considered charging; otherwise, it is discharging.

The current readings are taken from sensors that measure small voltage changes across known resistors. The system adjusts these readings with a calibration offset to get the actual current values.

All battery, panel, and charging data are also sent to Firebase. This allows users to check the SolarEye Security App and see the system’s battery level, charging status, and solar panel performance from anywhere.

### 4.2.2 Camera

The camera is the most important component to ensure proper security and surveillance is provided by the SolarEye Security System. To maximize power efficiency and provide the user of the system more control, the camera was programmed to operate in two modes of operation. Within these modes of operation the camera was tested and validated based on video upload latency and the difference between Real Event vs. Video Capture Ending.

The Video Upload Latency measures the time from when a motion event ends to when the corresponding video is uploaded and ready for the user to view in the app. Across multiple tests, the system achieved an average latency of 1.2951 seconds, well below the 3-second target, meaning users can access security footage almost immediately after an event. The data used to determine this values is in the table below:

Trials | 1 | 2 | 3 | 4 | 5 | 6 | 7 | 8 | 9 | 10
Time(s); | 1.28 | 1.30 | 1.27 | 1.31 | 1.29 | 1.32 | 1.28 | 1.29 | 1.20 | 1.29
Table 2: Video Upload Latency

The Real Event vs. Video Capture Ending measures the time between the end of a motion event and when the video recording stops. A 2-second waiting window was added to avoid cutting off events during short motion pauses, and a 0.5-second buffer from the MPU was included to cover processing delays. With these adjustments, the system averaged a delay of 4.03 seconds across ten trials, meeting the target of staying under 5 seconds and ensuring complete event capture. The data used to determine this values is in the table below:

Trials | 1 | 2 | 3 | 4 | 5 | 6 | 7 | 8 | 9 | 10
Time(s); | 4.00 | 4.10 | 3.95 | 4.05 | 4.00 | 4.15 | 4.05 | 4.00 | 4.10 | 4.05
Table 3: Video Upload Latency

### 4.2.3 Cooling System

To prevent overheating, the SolarEye Security System uses a small intake fan and a medium intake fan to cool the PCBs and MPU inside the housing. These fans run continuously to ensure stable operating temperatures.

A bash daemon script was developed to automatically run the intake fans in the background when the Raspberry Pi starts up. On boot, the script triggers specific GPIO pins that activate the Relay Module Controller PCB, which powers the cooling fans. This process ensures that fan operation is independent of the system’s mode of operation and begins immediately without requiring any user input.

Figure 1: Cooling System

The intake and exhaust fan currents were measured 10 times over a 30-second period during continuous operation to find an accurate average. The intake fan averaged 0.6 A, and the exhaust fan averaged 1.16 A. The power consumption calculated used Power
(W) = Voltage (V) x Current (A). Given the system voltage of 12.8 V, the intake fan consumes approximately 7.2 W, and the exhaust fan about 13.92 W. The data used to find the averages above is shown in the table below:
Trials | 1 | 2 | 3 | 4 | 5 | 6 | 7 | 8 | 9 | 10
Small Fan Current (A) | 0.58 | 0.60 | 0.59 | 0.61 | 0.60 | 0.59 | 0.61 | 0.60 | 0.59 | 0.60
Medium Fan Current (A) | 1.14 | 1.16 | 1.15 | 1.17 | 1.16 | 1.15 | 1.17 | 1.16 | 1.16 | 1.16

Table 4: Cooling System Current Measurements

Knowing the fans' power usage, combined with the Raspberry Pi’s mode of operation power consumption, allows for accurate estimation of the system’s total power draw and prediction of expected run time without recharging.

### 4.2.4 LED Deterrence

The SolarEye Security System has an LED deterrence feature that users can turn on or off from the SolarEye App. When enabled, the LED blinks quickly to act as a warning and help deter unwanted activity.

If deterrence is on and no motion or recording is happening, the LED blinks in the background. When motion is detected or recording starts, the LED stops blinking and stays fully ON. After the event ends, the blinking resumes if deterrence is still enabled.

In Motion Detection Mode and Low Power Mode, the LED blinks when idle and stays ON during motion events. In Livestream Mode, the LED stays ON the entire time while the stream is active, and blinking is paused.

This makes sure the LED provides both deterrence and clear status signals without affecting system performance.

### 4.2.5 Low Power Mode

The SolarEye Security System first mode of operation is Low Power Mode. Low Power Mode is designed to help extend battery life when needed while still allowing the user to get notified of when an event in the area of interest occurred. In this mode, the system is predicted to run for around 32.8 hours from a full battery without charging, providing basic security even when energy is limited.

While in Low Power Mode, the user experience is slightly different to save power. When motion is detected, the system turns on the LED, logs the time of the event occurrence and the duration of the detected motion, sends the information to firebase, and then turns off the LED. Users will still be able to see when motion events happen and how long they last, but full video recordings will not be available. Instead, users receive notifications with the event time and duration in the event history section of the Solareye App. This way, important security updates are still provided without using the extra power needed for video capture.

The system also keeps the LED deterrence feature active in Low Power Mode. When motion is detected, the LED will flash rapidly to help deter any unwanted activity. This provides a visible warning while using very little energy. The MPU will prioritize the LED being fully on if motion is detected and the LED Deterrence Mode is on. Once the motion detection sequence is completed the LED Deterrence will continue to rapidly flash as it did previously, until the LED Deterrence is turned off.

Low Power Mode can be turned on manually by the user at any time through the SolarEye Security App. However, it is also automatically activated if the system detects that the battery level has dropped below 20%. A voltage sensor connected to the ADC continuously monitors the battery status, and once it falls under this threshold, the system will switch into Low Power Mode to preserve energy. This process uses the same voltage sensor readings and charging statistics that were discussed earlier. By doing this, the SolarEye Security System ensures longer operation times and keeps users informed even during low-power situations.


Figure 2: LED Deterrence Active

### 4.2.6 Motion Detection Mode

The SolarEye Security System default mode of operation is Motion Detection Mode. Motion Detection Mode is designed to provide reliable surveillance while balancing power consumption and fast event response. In this mode, the system is predicted to run for around 30.69 hours from a full battery without charging, providing full security coverage during normal use.

While in Motion Detection Mode, the system uses a tuned PIR sensor to continuously monitor the area of interest. When motion is detected, the camera is powered on and begins recording video almost immediately. The delay between motion detection and the start of video capture was measured at 0.2082 seconds, determined by measuring the time between PIR activation and the start of USB camera recording. Recording continues until no motion is detected for at least 2 seconds, allowing short pauses in movement without interrupting event capture. Users will receive notifications when a motion event occurs, along with access to full video recordings through the SolarEye Security App’s event history.

Trials | 1 | 2 | 3 | 4 | 5 | 6 | 7 | 8 | 9 | 10
Time(s); | 0.207 | 0.209 | 0.208 | 0.210 | 0.208 | 0.207 | 0.209 | 0.208 | 0.208 | 0.208
Table 5: Video Upload Latency

The system also captures a frame from the video recording when motion is detected and sends it with a timestamp to the cloud database. This helps provide near-real-time updates without waiting for the full video upload. After recording stops, the video is saved locally in h264 format, converted to mp4, and uploaded to Firebase Storage, allowing users to easily view the captured footage from their mobile device. A terminal output showing these steps is below:


Figure 3: Motion Detection Mode Pipeline Terminal

Motion Detection Mode operates automatically once the system is powered on, but the user can modify certain settings—such as the motion detection timeout—through the SolarEye Security App if preferred. By combining low idle power consumption with rapid response to motion, the SolarEye Security System ensures dependable operation throughout typical daily cycles without the need for frequent recharging.

### 4.2.7 Live Streaming

The SolarEye Security System also offers a Livestream Mode, which can be manually enabled by the user through the SolarEye App. Livestream Mode is designed to provide real-time video access to the system’s camera when needed for active monitoring. In this mode, the system is predicted to run for approximately 22.18 hours from a full battery without charging, due to the higher power demands of continuous video streaming.

When a user activates Live Stream Mode, the SolarEye App sends a request that starts an HTTP server on the Raspberry Pi. The Pi then begins transmitting live video using the HLS (HTTP Live Streaming) protocol. A unique HTTP stream link is generated and sent back to the app, allowing the user to access the live feed directly by clicking on the provided link.

The system’s livestream delay was also measured to assess performance. To evaluate the delay, a single livestream session was started and ten separate events were triggered within the camera’s field of view. For each event, a timer was started when the motion occurred and stopped once the event appeared on the livestream. The average livestream delay across these trials was approximately 7.8 seconds, exceeding the desired target of less than 5 seconds and resulting in a failed outcome for this test. The values from the trials are below:

Trials | 1 | 2 | 3 | 4 | 5 | 6 | 7 | 8 | 9 | 10
Time(s); | 7.5 | 7.8 | 8.0 | 7.7 | 7.9 | 8.1 | 7.6 | 7.8 | 7.7 | 7.8
Table 6: Video Upload Latency

Despite the higher delay, Livestream Mode still provides users with on-demand access to their security feed. Due to the intensive power and bandwidth usage associated with real-time video streaming, Livestream Mode remains a user-activated feature rather than a default operation to preserve system resources when not actively monitoring.

The livestream is shown through a basic HTML page with an embedded video player. When users start a livestream, the player connects to the HLS stream link and shows the live video inside the SolarEye App or a web browser. HLS.js is used to make sure the video plays smoothly on different devices, giving users quick and easy access to the live feed.


Figure 4: Livestream UI Layout

### 4.2.8 Firebase Database

The database used for this subsystem was Firebase. The reason for choosing this cloud database was its ability to ease in integration with the SolarEye Security App. Furthermore, Firebase provides a realtime database, which can provide notifications and real-time updates to users of the SolarEye Security App. The Firebase Storage Database, provides long-term event history for video footage storage. These events are able to be accessed by users of the SolarEye Security App via url tokens embedded in the video footage. To ensure the security of the two databases, Firebase Authentication and security rules are used. These measures prevent unwanted access to either database. Furthermore, the data sent and stored in the databases is encrypted.

In Firebase video storage was saved in Firebase Storage, and saved as mp4 files with an access token allowing the user to view the video from a browser without an external video player. The video access tokens were packaged with a timestamp in Cloud Firestore for the app’s event history. An image of the database structure for event history is below:

Figure #: Firestore Motion Detection Data Structure

The System controls that enable the modes of operation, and the led deterrence were also triggered by the app via cloud firestore. The MPU software used a case statement to automatically change which mode of operation was active via a numerical state of 0, 1, or 2. If the value of the modes of operation state was 0 it would trigger low power mode, 1 would trigger motion detection, and 2 would trigger live streaming. The default case was set to any value received by the MPU from firestore for the field that was not 0, 1 or 2. In the default case, it enabled motion detection.

### 4.3 Subsystem Conclusion

The Edge Processing Unit Subsystem is the core of the SolarEye Security System, connecting sensors, the camera, and user controls into one reliable platform. Using a Raspberry Pi, the system collects motion data, monitors battery and solar performance, manages video recordings, and controls hardware like cooling fans and LED deterrence. It supports different modes — Low Power, Motion Detection, and Livestream — giving users the flexibility to manage power and performance based on their needs. With real-time cloud updates through Firebase, users get instant alerts, event history, and remote control access.Overall, the subsystem makes the SolarEye Security System dependable, efficient, and easy to manage from anywhere.

## 5. Application Subsystem Report - Zayan Prasla

### 5.1 Android Application and Database Introduction

The Android application offers an easy-to-use user interface to manage the SolarEye Security System. The application allows authorized users to view motion-detected events directly from the app and adjust modes of operations/control system parts in real-time from remote locations.

This is supported by Firebase, a cloud-based database that securely stores user credentials, system logs, and configuration data. Using Firebase, the application is equipped with secure email verification and two-step authentication.

With the integration of mobile technology and cloud storage, the SolarEye Security System app has made it all smooth and quick in handling the security systems. This section presents an overview of the Android application and database integration that are used in this project.
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

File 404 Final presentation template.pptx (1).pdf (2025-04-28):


# ECEN 404 Final Presentation Team 65: Solar Playground with Security System

### Team Members: Zayan Prasla, Alex Allahar, Jackson Kitchel, Victor Igbokwe Sponsor: Wonhyeok Jang TA: Zian Wang

# Problem Overview

A solar-powered security system with a motion-detecting camera. This system provides near real-time video feeds and sends automated alerts for suspicious activity through a mobile app, enhancing safety in these areas. It solves the problem of unreliable surveillance in remote or off-grid locations by offering an autonomous, low-maintenance

solution.
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

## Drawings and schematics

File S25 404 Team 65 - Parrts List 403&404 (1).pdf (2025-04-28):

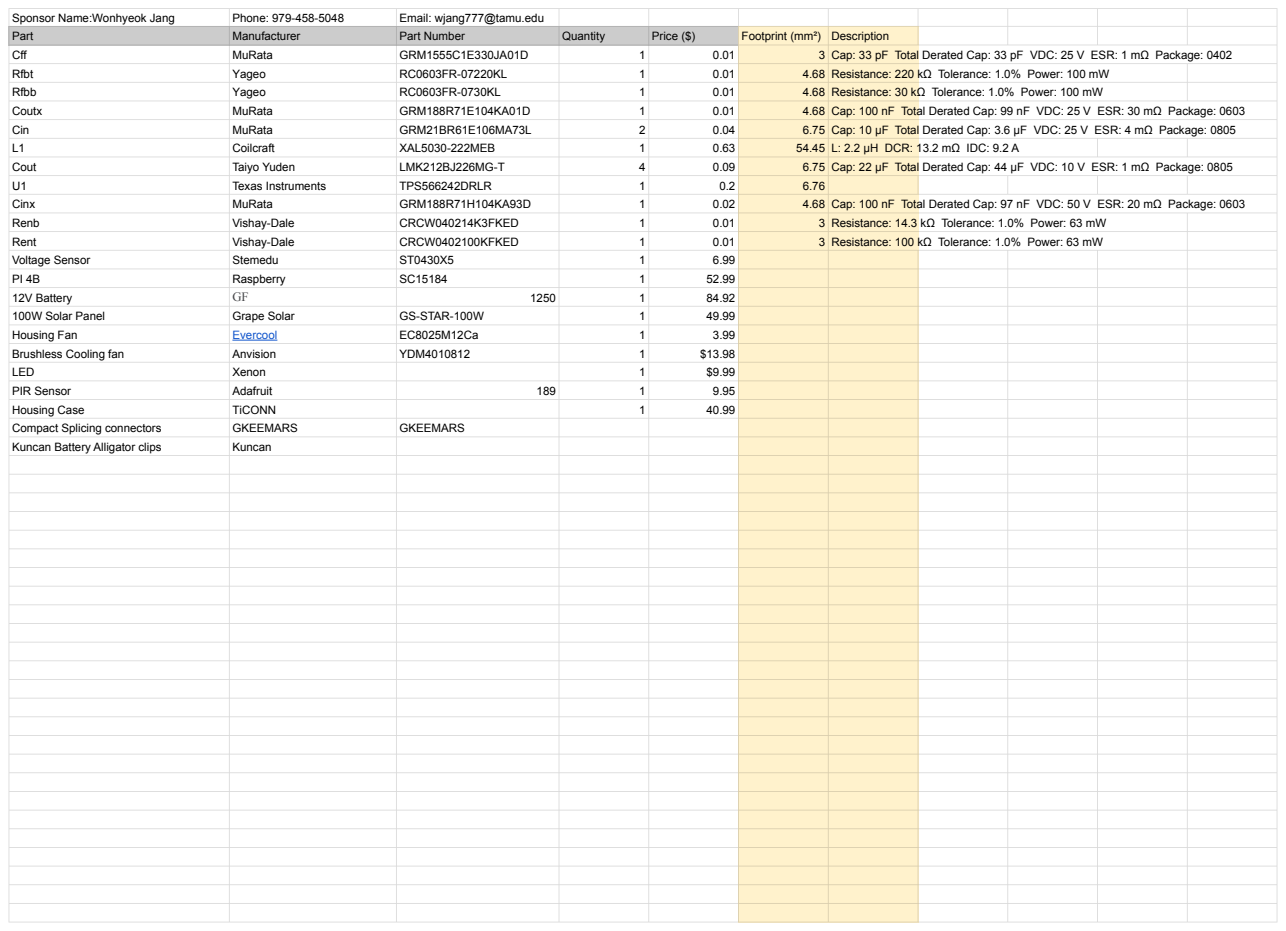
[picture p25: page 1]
Sponsor Name:Wonhyeok Jang; Phone: 979-458-5048; Email: wjang777@tamu.edu; Part; Manufacturer; Part Number; Quantity; Price ($); Footprint (mm²) Description; Cff; MuRata; GRM1555C1E330JA01D; 3 Cap: 33 pF Total Derated Cap: 33 pF VDC: 25 V ESR: 1 mΩ Package: 0402; Rfbt; Yageo; 4.68 Resistance: 220 kΩ Tolerance: 1.0% Power: 100 mW; Rfbb; 4.68 Resistance: 30 kΩ Tolerance: 1.0% Power: 100 mW; Coutx; GRM188R71E104KA01D; 4.68 Cap: 100 nF Total Derated Cap: 99 nF VDC: 25 V ESR: 30 mΩ Package: 0603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

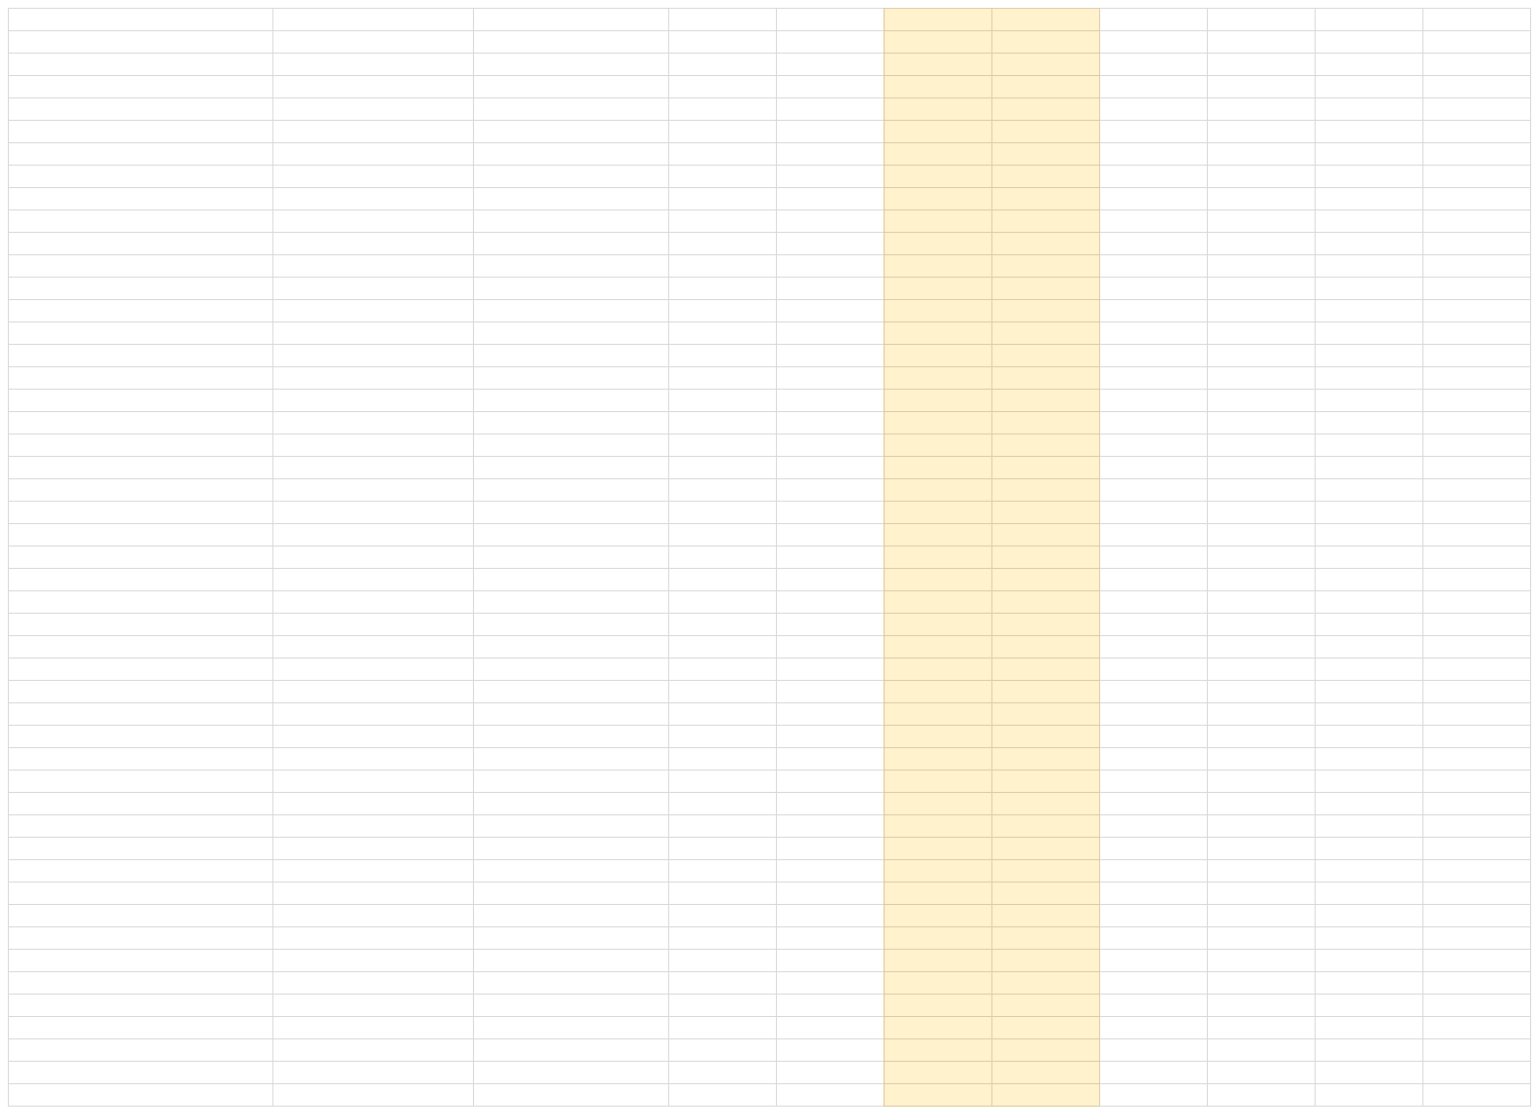
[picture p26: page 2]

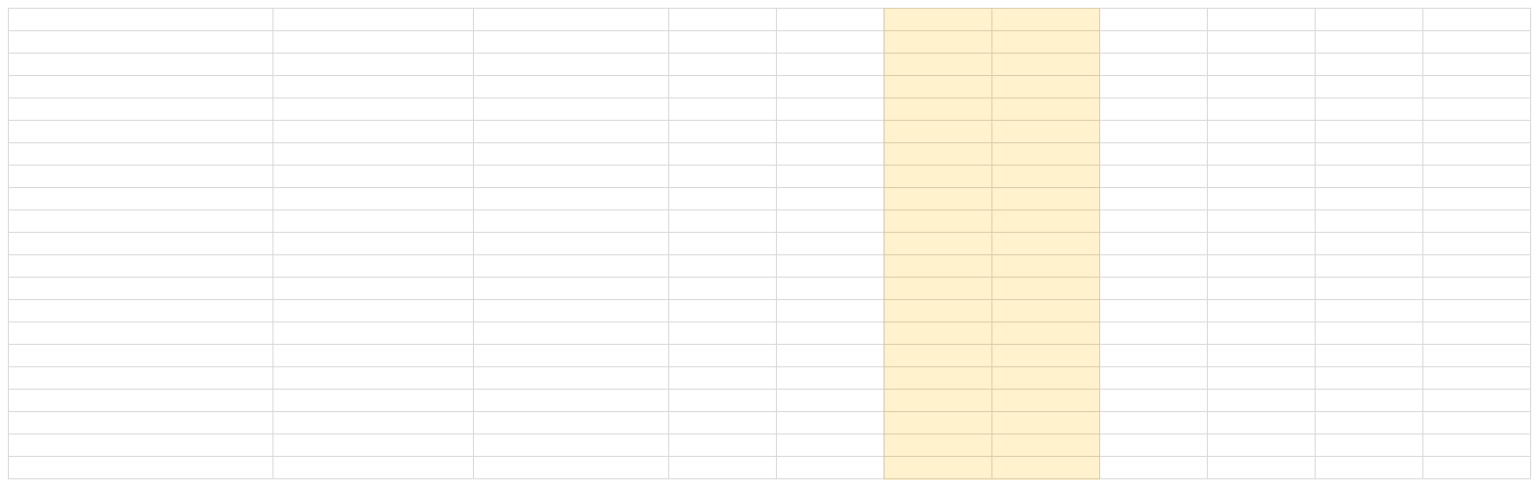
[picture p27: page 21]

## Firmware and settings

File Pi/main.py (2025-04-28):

import cv2
import os
import time
import firebase_admin
from firebase_admin import credentials, db, storage
from gpiozero import MotionSensor
from signal import pause

# Firebase Initialization
cred = credentials.Certificate("firebase_credentials.json")  # Update with your Firebase credentials JSON file
firebase_admin.initialize_app(cred, {
    'databaseURL': 'https://gpiotest-default-rtdb.firebaseio.com/',  # Replace with your Firebase database URL
    'storageBucket': 'gpiotest.appspot.com'  # Use your Firebase Storage bucket
})

# Reference to Firebase Realtime Database location
ref = db.reference('pir_sensor_data')

# PIR Sensor setup
pir = MotionSensor(18)  # GPIO pin where PIR sensor is connected

# Define the output directories
output_dir_video = 'videos'
output_dir_frames = 'extracted_frames'
output_dir_preprocessed = 'preprocessed_frames'

# Ensure directories exist
os.makedirs(output_dir_video, exist_ok=True)
os.makedirs(output_dir_frames, exist_ok=True)
os.makedirs(output_dir_preprocessed, exist_ok=True)

# Global variable to manage motion detection state
motion_detected = False

def capture_video():
    global motion_detected
    motion_detected = True  # Set motion_detected to True when video capture starts

    # Video capture from USB camera
    camera_index = 0
    cap = cv2.VideoCapture(camera_index)

    # Check if the camera opened successfully
    if not cap.isOpened():
        print("Error: Could not open camera.")
        return

    # Define output video file path with a unique timestamp
    output_filename = os.path.join(output_dir_video, f'output_{time.strftime("%Y%m%d_%H%M%S")}.avi')
    fourcc = cv2.VideoWriter_fourcc(*'XVID')
    out = cv2.VideoWriter(output_filename, fourcc, 20.0, (640, 480))

    # Capture video for 10 seconds
    start_time = time.time()
    while True:
        ret, frame = cap.read()
        if ret:
            out.write(frame)
            if time.time() - start_time > 10:
                break
        else:
            break

    # Release everything
    cap.release()
    out.release()
    cv2.destroyAllWindows()

    # Check if the video file was created successfully
    if os.path.exists(output_filename):
        # Upload video to Firebase Storage
        upload_video_to_firebase(output_filename)
        # Extract and preprocess frames from the video
        extract_and_preprocess_frames(output_filename)
    else:
        print("Error: Video file was not created.")

    # Delay for 1 minute before allowing detection again
    print("Waiting for 1 minute before allowing new motion detection...")
    time.sleep(60)
    motion_detected = False  # Reset the motion_detected flag after the delay

# Upload the video to Firebase Storage
def upload_video_to_firebase(video_path):
    bucket = storage.bucket()
    video_filename = os.path.basename(video_path)
    blob = bucket.blob(f'videos/{video_filename}')
    blob.upload_from_filename(video_path)
    blob.make_public()
    print(f'Video uploaded to Firebase with URL: {blob.public_url}')

def extract_and_preprocess_frames(video_path):
    cap = cv2.VideoCapture(video_path)
    frame_count = 0
    max_frames = 250  # Limit to 250 frames

    # Clear existing frames before extraction
    for folder in [output_dir_frames, output_dir_preprocessed]:
        for filename in os.listdir(folder):
            file_path = os.path.join(folder, filename)
            try:
                os.remove(file_path)
            except Exception as e:
                print(f"Error removing file {file_path}: {e}")

    while frame_count < max_frames:
        ret, frame = cap.read()
        if not ret:
            break

        # Save raw frame to extracted_frames folder
        frame_filename = os.path.join(output_dir_frames, f'frame_{frame_count:04d}.jpg')
        cv2.imwrite(frame_filename, frame)

        # Preprocess and save frame
        preprocessed_frame = preprocess_frame(frame)
        preprocessed_filename = os.path.join(output_dir_preprocessed, f'frame_{frame_count:04d}.jpg')
        cv2.imwrite(preprocessed_filename, preprocessed_frame)

        frame_count += 1

    cap.release()
    print(f'Extracted and preprocessed {frame_count} frames to {output_dir_frames} and {output_dir_preprocessed}')

# Preprocess a single frame
def preprocess_frame(frame):
    # Resize to fixed size (e.g., 640x480)
    frame_resized = cv2.resize(frame, (640, 480))
    # Convert to grayscale
    frame_gray = cv2.cvtColor(frame_resized, cv2.COLOR_BGR2GRAY)
    # Normalize pixel values
    frame_normalized = frame_gray / 255.0  # Scale pixel values to [0, 1]
    return (frame_normalized * 255).astype('uint8')  # Convert back to uint8 for saving

# Functions to handle motion events and push data to Firebase
def motion_function():
    if not motion_detected:  # Check if motion is already detected
        data = {
            'motion': 'detected',
            'timestamp': time.strftime('%Y-%m-%d %H:%M:%S')
        }
        ref.push(data)
        print("Motion detected and data pushed to Firebase")

        # Start video capture when motion is detected
        capture_video()

def no_motion_function():
    data = {
        'motion': 'stopped',
        'timestamp': time.strftime('%Y-%m-%d %H:%M:%S')
    }
    ref.push(data)
    print("Motion stopped and data pushed to Firebase")

# Assign functions to motion events
pir.when_motion = motion_function
pir.when_no_motion = no_motion_function

# Wait for PIR sensor events
print("Monitoring GPIO pin for sensor activation...")
pause()

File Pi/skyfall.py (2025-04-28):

#!/usr/bin/env python3
import time
import os
import socket
import subprocess
import threading
import atexit
from collections import deque

import board
import busio
import adafruit_ads1x15.ads1115 as ADS
from adafruit_ads1x15.analog_in import AnalogIn

import firebase_admin
from firebase_admin import credentials, firestore, storage
from gpiozero import MotionSensor, LED
from flask import Flask, Response, send_from_directory, abort

# ——— Configuration ——————————————————————————————————————————————
CRED_PATH        = "solareye_credentials.json"
STORAGE_BUCKET   = "solareye-security-system.firebasestorage.app"
HLS_FOLDER       = "/tmp/hls"
FIFO_PATH        = "/tmp/vidpipe.h264"
LED_BLINK_ON     = 0.1    # deterrence blink on duration (s)
LED_BLINK_OFF    = 0.1    # deterrence blink off duration (s)
HTTP_PORT        = 8000   # port for HTTP

# Debounce settings
PIR_DEBOUNCE     = 0.5    # seconds between PIR events
last_pir_event   = 0.0

# ——— ADC calibration (optional telemetry) ——————————————————————————————
DIVIDER_RATIO_A0     = 21.0
BATTERY_NOMINAL_V    = 12.8
CHARGING_THRESHOLD_V = 13.0
DIVIDER_RATIO_A2     = 40.0
V_ZERO               = 2.5
SENSITIVITY          = 0.1

# ——— ADC Setup ————————————————————————————————————————————————
i2c = busio.I2C(board.SCL, board.SDA)
ads = ADS.ADS1115(i2c)
chan_a0 = AnalogIn(ads, ADS.P0)
chan_a1 = AnalogIn(ads, ADS.P1)
chan_a2 = AnalogIn(ads, ADS.P2)
chan_a3 = AnalogIn(ads, ADS.P3)
window_a1 = deque(maxlen=10)
window_a3 = deque(maxlen=10)

def get_telemetry():
    """(Optional) read & smooth voltages/currents."""
    v0 = chan_a0.voltage
    battery_v = v0 * DIVIDER_RATIO_A0
    soc = max(0.0, min((battery_v / BATTERY_NOMINAL_V) * 100.0, 100.0))
    status = "Charging" if battery_v > CHARGING_THRESHOLD_V else "Discharging"

    v1 = chan_a1.voltage
    raw_i1 = (v1 - V_ZERO) / SENSITIVITY
    window_a1.append(raw_i1)
    i1 = sum(window_a1) / len(window_a1)

    v2 = chan_a2.voltage
    panel_v = v2 * DIVIDER_RATIO_A2

    v3 = chan_a3.voltage
    raw_i3 = (v3 - V_ZERO) / SENSITIVITY
    window_a3.append(raw_i3)
    i3 = sum(window_a3) / len(window_a3)

    return {
        'battery_voltage': round(battery_v, 3),
        'battery_soc':      round(soc, 1),
        'battery_status':   status,
        'panel_voltage':    round(panel_v, 3),
        'current_1':        round(i1, 3),
        'current_2':        round(i3, 3),
    }

# ——— Firebase Initialization —————————————————————————————————————
cred = credentials.Certificate(CRED_PATH)
firebase_admin.initialize_app(cred, {'storageBucket': STORAGE_BUCKET})
db               = firestore.client()
bucket           = storage.bucket()
pir_sensor_ref   = db.collection('pir_sensor_data')
video_sensor_ref = db.collection('video_sensor_data')
mode_ref         = db.collection('control').document('operation_mode')
led_control_ref  = db.collection('control').document('led_control')
livestream_ref   = db.collection('control').document('livestream')

# Initialize control docs: set mode=1, led_control=0
try:
    led_control_ref.set({'state': 0}, merge=True)
    mode_ref.set({'mode': 1}, merge=True)
except Exception as e:
    print(f"[INIT] Error initializing control docs: {e}")

# ——— Hardware Setup ————————————————————————————————————————————
pir = MotionSensor(14)
led = LED(17)
led.off()
atexit.register(led.off)  # ensure LED off on exit

# ——— State Variables ————————————————————————————————————————————
current_mode      = None
motion_active     = False
recording_process = None
ffmpeg_process    = None

# ——— Mode 0: motion-only detection ——————————————————————————————————
def mode0_motion():
    global motion_active, last_pir_event
    now = time.time()
    if now - last_pir_event < PIR_DEBOUNCE:
        return
    last_pir_event = now

    motion_active = True
    led.on()
    ts = time.strftime('%Y-%m-%d %H:%M:%S')
    print(f"[{ts}] Mode0: motion detected, LED ON")
    try:
        pir_sensor_ref.add({'motion': 'detected', 'timestamp': ts})
        video_sensor_ref.add({'video_url': '', 'timestamp': ts})
        print(f"[Mode0] logged to Firestore")
    except Exception as e:
        print(f"[Mode0] log error: {e}")

def mode0_no_motion():
    global motion_active, last_pir_event
    now = time.time()
    if now - last_pir_event < PIR_DEBOUNCE:
        return
    last_pir_event = now

    motion_active = False
    led.off()
    ts = time.strftime('%Y-%m-%d %H:%M:%S')
    print(f"[{ts}] Mode0: motion stopped, LED OFF")
    try:
        pir_sensor_ref.add({'motion': 'stopped', 'timestamp': ts})
        video_sensor_ref.add({'video_url': '', 'timestamp': ts})
        print(f"[Mode0] stop logged to Firestore")
    except Exception as e:
        print(f"[Mode0] stop log error: {e}")

# ——— Mode 1: video recording ——————————————————————————————————————
def start_recording():
    global recording_process
    now = time.time()
    if now - last_pir_event < PIR_DEBOUNCE:
        return None
    ts   = time.strftime('%Y%m%d_%H%M%S')
    h264 = f"/tmp/video_{ts}.h264"
    mp4  = f"/tmp/video_{ts}.mp4"
    recording_process = subprocess.Popen([
        "libcamera-vid","-t","0","--width","1280","--height","720",
        "--framerate","24","--output", h264
    ], stdout=subprocess.DEVNULL, stderr=subprocess.DEVNULL)
    led.on()
    print(f"[{ts}] Mode1: recording started, LED ON")
    return (h264, mp4)

def stop_recording(clip):
    global recording_process
    if recording_process:
        recording_process.terminate()
        recording_process.wait()
        recording_process = None
    if clip:
        h264, mp4 = clip
        subprocess.run([
            "ffmpeg","-y","-framerate","24","-i",h264,
            "-c:v","libx264","-preset","fast","-pix_fmt","yuv420p",mp4
        ], stdout=subprocess.DEVNULL, stderr=subprocess.DEVNULL)
        try:
            blob = bucket.blob(f"videos/{os.path.basename(mp4)}")
            blob.upload_from_filename(mp4)
            blob.make_public()
            ts = time.strftime('%Y-%m-%d %H:%M:%S')
            video_sensor_ref.add({'video_url': blob.public_url, 'timestamp': ts})
            print(f"[{ts}] Mode1: uploaded & logged to Firestore")
        except Exception as e:
            print(f"[Mode1] upload error: {e}")
        for f in (h264, mp4):
            try: os.remove(f)
            except: pass
    led.off()
    print("Mode1: recording stopped, LED OFF")

# ——— Mode 2: HLS livestream ———————————————————————————————————————
app = Flask(__name__)
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

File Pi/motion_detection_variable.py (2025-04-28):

import cv2
import os
import time
import firebase_admin
from firebase_admin import credentials, db, storage
from gpiozero import MotionSensor
from signal import pause
import os  # Make sure os is imported
import sys

# Firebase Initialization
cred = credentials.Certificate("firebase_credentials.json")  # Update with your Firebase credentials JSON file
firebase_admin.initialize_app(cred, {
    'databaseURL': 'https://gpiotest-default-rtdb.firebaseio.com/',  # Replace with your Firebase database URL
    'storageBucket': 'gpiotest.appspot.com'  # Use your Firebase Storage bucket
})

# Reference to Firebase Realtime Database location
ref = db.reference('pir_sensor_data')

# PIR Sensor setup
pir = MotionSensor(18)  # GPIO pin where PIR sensor is connected

# Define output directories
output_dir_video = 'videos'
output_dir_frames = 'extracted_frames'
output_dir_preprocessed = 'preprocessed_frames'
output_dir_images = 'motion_images'

# Ensure directories exist
os.makedirs(output_dir_video, exist_ok=True)
os.makedirs(output_dir_frames, exist_ok=True)
os.makedirs(output_dir_preprocessed, exist_ok=True)
os.makedirs(output_dir_images, exist_ok=True)

# Global variables
motion_detected = False
continuous_mode = False  # Tracks whether continuous mode is enabled
last_motion_time = None  # Tracks when motion was last detected

def initial_capture():
    """Captures a single image and uploads it to Firebase Storage."""
    camera_index = 0
    cap = cv2.VideoCapture(camera_index)
    if not cap.isOpened():
        print("Error: Could not open camera for initial capture.")
        return

    ret, frame = cap.read()
    if ret:
        image_path = os.path.join(output_dir_images, f'motion_image_{time.strftime("%Y%m%d_%H%M%S")}.jpg')
        cv2.imwrite(image_path, frame)
        upload_image_to_firebase(image_path)
    else:
        print("Error: Could not capture image.")
    cap.release()

def upload_image_to_firebase(image_path):
    bucket = storage.bucket()
    image_filename = os.path.basename(image_path)
    blob = bucket.blob(f'images/{image_filename}')
    blob.upload_from_filename(image_path)
    blob.make_public()
    print(f'Image uploaded to Firebase with URL: {blob.public_url}')

def detect_motion_in_frame(frame, previous_frame):
    """
    Detects motion by comparing the current frame with the previous frame.
    Returns True if motion is detected, False otherwise.
    """
    if previous_frame is None:
        return False

    # Convert frames to grayscale
    gray_frame = cv2.cvtColor(frame, cv2.COLOR_BGR2GRAY)
    gray_prev_frame = cv2.cvtColor(previous_frame, cv2.COLOR_BGR2GRAY)

    # Compute absolute difference between frames
    diff = cv2.absdiff(gray_prev_frame, gray_frame)

    # Threshold the difference to identify motion areas
    _, threshold = cv2.threshold(diff, 25, 255, cv2.THRESH_BINARY)
    motion_area = cv2.countNonZero(threshold)

    # Define a minimum motion area to detect motion
    min_motion_area = 5000  # Adjust this value as needed

    return motion_area > min_motion_area

def capture_video():
    """Captures video and stops after no motion is detected for 5 seconds."""
    global motion_detected, last_motion_time
    motion_detected = True  # Set motion_detected to True when video capture starts

    # Video capture from USB camera
    camera_index = 0
    cap = cv2.VideoCapture(camera_index)
    if not cap.isOpened():
        print("Error: Could not open camera.")
        return

    # Set camera parameters for better low-light capture (optional)
    cap.set(cv2.CAP_PROP_EXPOSURE, -6)  # Adjust exposure for low light (experiment with value)
    cap.set(cv2.CAP_PROP_GAIN, 0.5)  # Adjust gain to improve brightness in low light (adjust as needed)

    output_filename = os.path.join(output_dir_video, f'output_{time.strftime("%Y%m%d_%H%M%S")}.avi')
    fourcc = cv2.VideoWriter_fourcc(*'XVID')
    out = cv2.VideoWriter(output_filename, fourcc, 20.0, (640, 480))

    print("Recording video based on motion detection in frames...")
    previous_frame = None
    motion_stopped_time = None
    frame_count = 0  # Track the number of frames written to the video

    # Start video capture and continuously check for motion
    while True:
        ret, frame = cap.read()
        if not ret:
            print("Error: Could not read frame from camera.")
            break

        # Detect motion in the current frame
        motion_in_frame = detect_motion_in_frame(frame, previous_frame)
        previous_frame = frame.copy()

        if motion_in_frame:
            out.write(frame)  # Write the frame to the output file
            frame_count += 1  # Increment frame count
            motion_stopped_time = None  # Reset motion stopped timer
            last_motion_time = time.time()  # Update last motion time
        else:
            # If motion stops, start the timer
            if motion_stopped_time is None:
                motion_stopped_time = time.time()
            elif time.time() - motion_stopped_time >= 5:  # Wait 5 seconds with no motion
                print("No motion detected for 5 seconds. Stopping recording...")
                break

    cap.release()
    out.release()
    print("Video recording ended.")

    # Calculate video duration in seconds
    video_duration = frame_count / 20.0  # FPS is 20.0, as set when writing the video
    print(f"Video duration: {video_duration:.2f} seconds.")

    if os.path.exists(output_filename):
        upload_video_to_firebase(output_filename)
        extract_and_preprocess_frames(output_filename)
    else:
        print("Error: Video file was not created.")

def upload_video_to_firebase(video_path):
    bucket = storage.bucket()
    video_filename = os.path.basename(video_path)
    blob = bucket.blob(f'videos/{video_filename}')
    blob.upload_from_filename(video_path)
    blob.make_public()
    print(f'Video uploaded to Firebase with URL: {blob.public_url}')
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

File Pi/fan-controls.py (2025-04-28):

import RPi.GPIO as GPIO
import time

# Define GPIO pins
MOSFET_GATE_PIN = 17  # Controls fan power (on/off)
PWM_PIN = 18          # Controls fan speed (PWM signal)

# Setup GPIO mode and pins
GPIO.setmode(GPIO.BCM)
GPIO.setup(MOSFET_GATE_PIN, GPIO.OUT)
GPIO.setup(PWM_PIN, GPIO.OUT)

# Initially, power off the fan and set PWM duty cycle to 0%
GPIO.output(MOSFET_GATE_PIN, GPIO.LOW)
frequency = 250  # PWM frequency in Hz (adjust as needed for your fan)
pwm = GPIO.PWM(PWM_PIN, frequency)
pwm.start(0)

print("Enter 'on' to turn on the fan, 'off' to turn it off, 'speed <0-100>' to set fan speed, or 'exit' to quit.")

try:
    while True:
        command = input("Command: ").strip().lower()

        if command == "on":
            # Turn on the fan by enabling power via MOSFET
            GPIO.output(MOSFET_GATE_PIN, GPIO.HIGH)
            print("Fan turned ON.")

        elif command == "off":
            # Turn off the fan by cutting power and setting PWM duty cycle to 0
            GPIO.output(MOSFET_GATE_PIN, GPIO.LOW)
            pwm.ChangeDutyCycle(0)
            print("Fan turned OFF.")

        elif command.startswith("speed"):
            # Command should be in the form "speed <value>"
            try:
                parts = command.split()
                if len(parts) != 2:
                    raise ValueError("Invalid format")
                speed = float(parts[1])
                if speed < 0 or speed > 100:
                    print("Speed value must be between 0 and 100.")
                else:
                    # Set PWM duty cycle to adjust fan speed
                    pwm.ChangeDutyCycle(speed)
                    print(f"Fan speed set to {speed}% duty cycle.")
            except Exception as e:
                print("Usage: speed <value>  (where <value> is a number between 0 and 100)")

        elif command == "exit":
            break

        else:
            print("Invalid command. Use 'on', 'off', 'speed <value>', or 'exit'.")

except KeyboardInterrupt:
    print("\nExiting...")

finally:
    pwm.stop()           # Stop PWM output
    GPIO.cleanup()       # Clean up GPIO settings
    print("GPIO cleaned up.")
